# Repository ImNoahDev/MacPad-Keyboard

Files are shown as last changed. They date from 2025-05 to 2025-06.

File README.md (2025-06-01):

# The MacPad

The MacPad is a full sized keyboard designed for use with a Mac. The keyboard has 2 rotary encoders and a single fader for custom controls. The keyboard is designed to be used with QMK,

It can use any Alps or Cherry MX switches with optional through hole LEDs for backlighting.

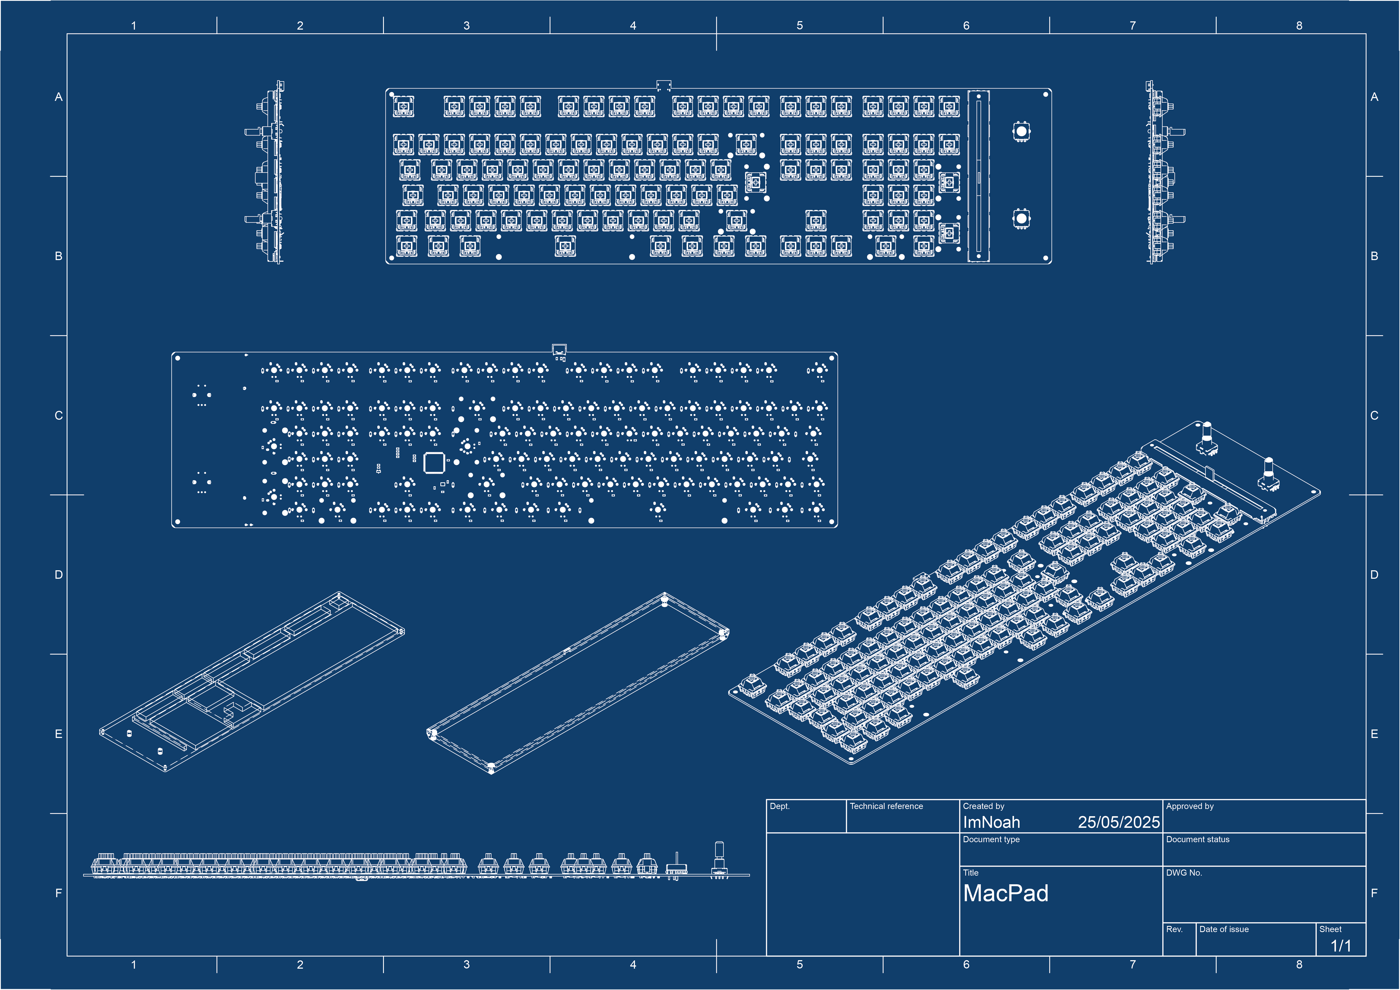
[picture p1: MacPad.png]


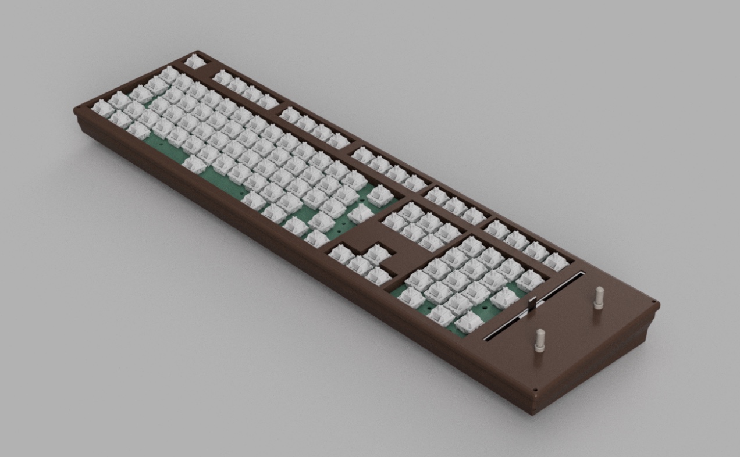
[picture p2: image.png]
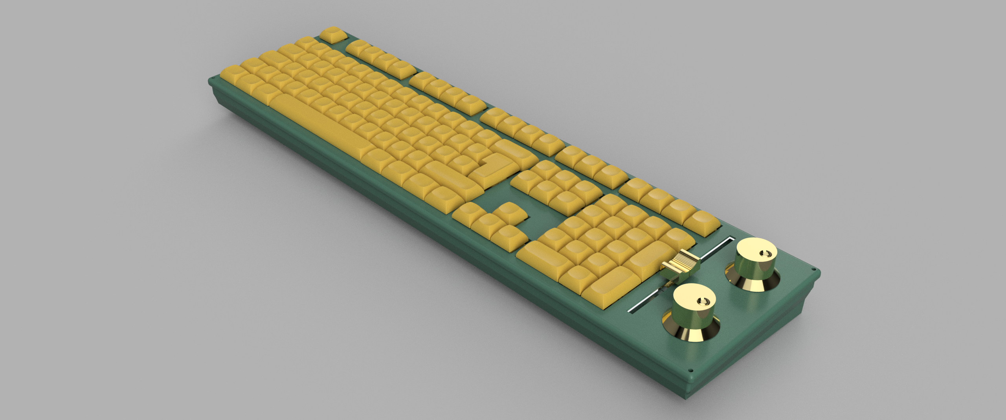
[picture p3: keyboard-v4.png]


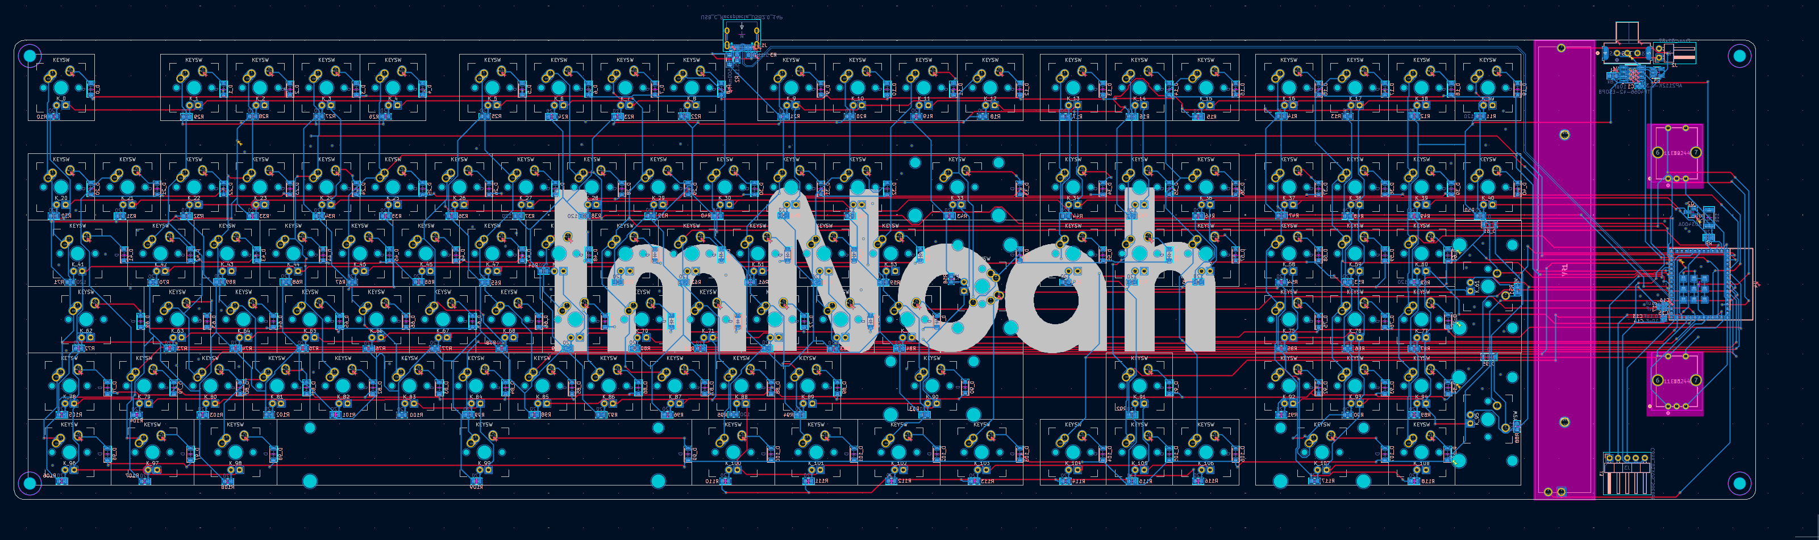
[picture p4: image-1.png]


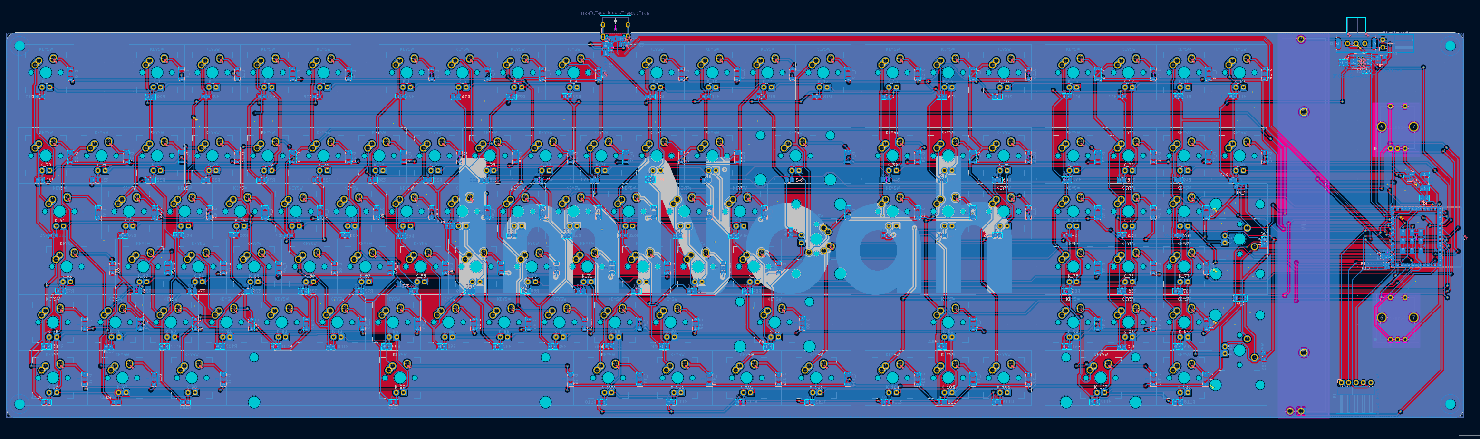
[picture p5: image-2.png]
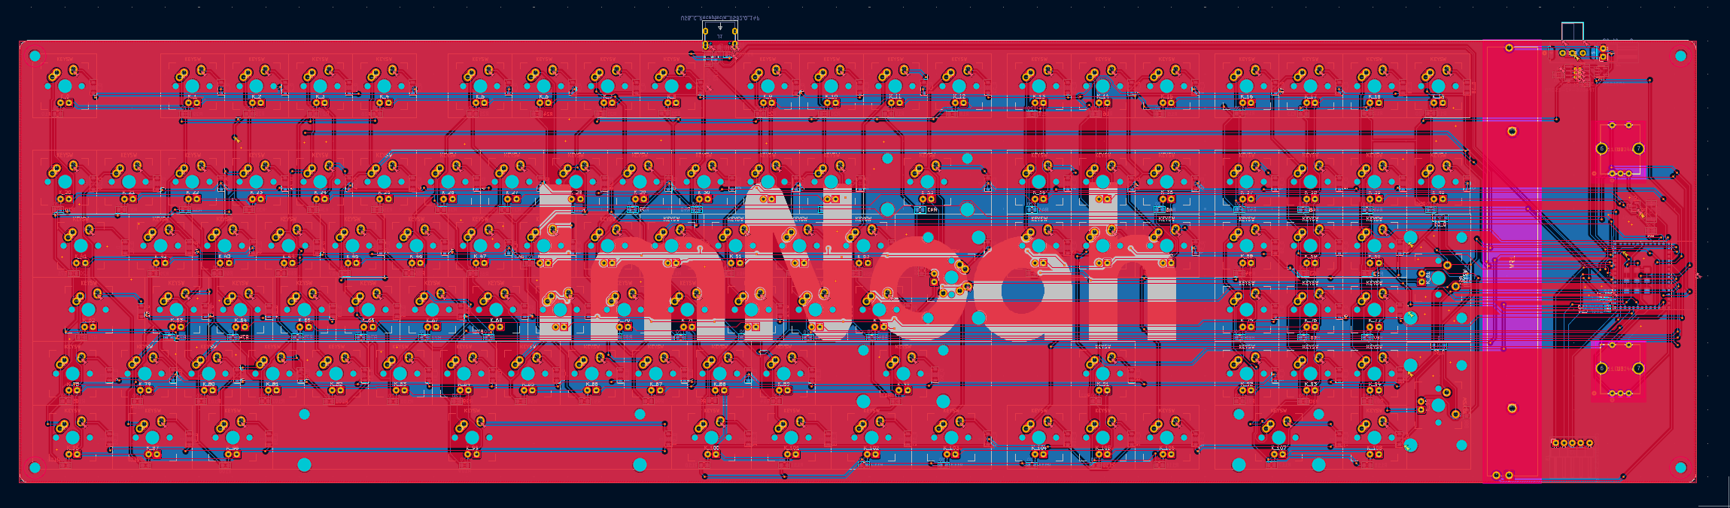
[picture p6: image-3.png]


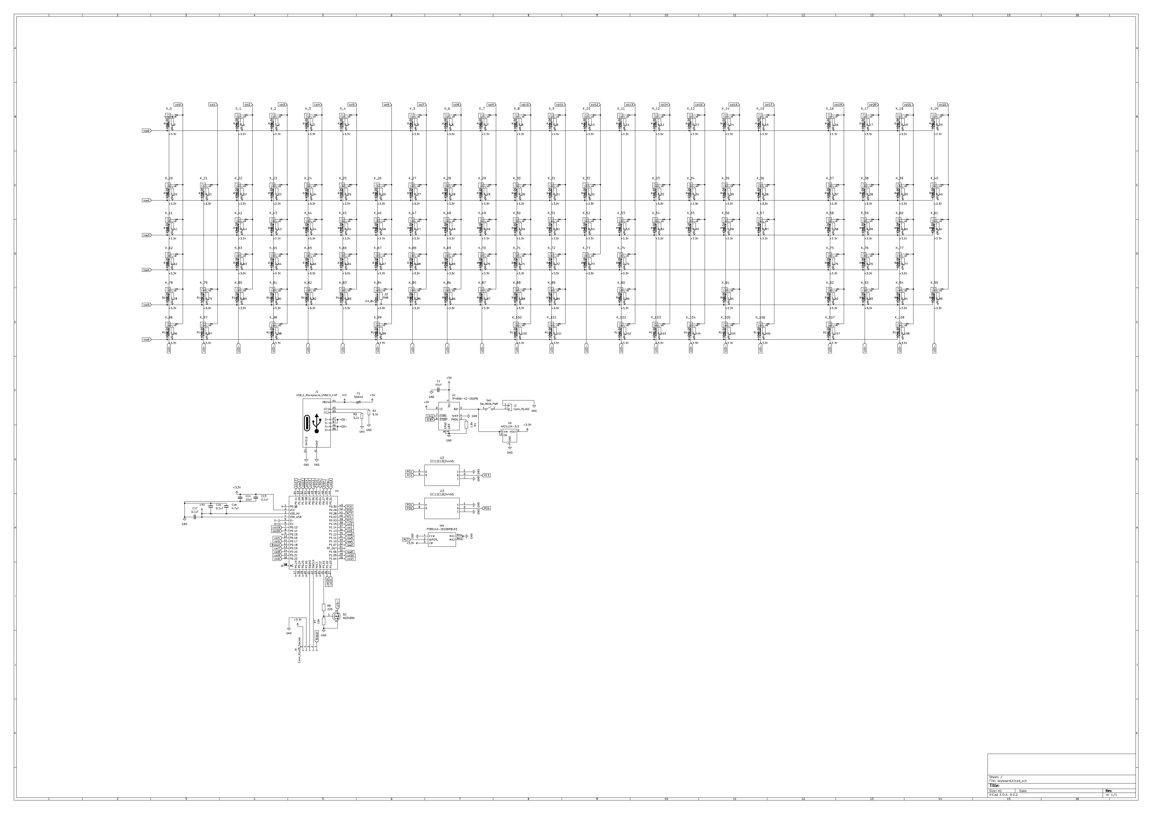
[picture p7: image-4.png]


## Assembly

The Plate must first be soldered underneath the switches (see plate.ai)

The PCB screws into the base with M3 screws and the top of the case screws ontop.

QMK firmware + configuration must be flashed using the macpad.hex file. The reset button can be pressed on the keyboard to put it into flashing mode and to flash the firmware. the F18 button can then be used as a reset button after the initial flash.

## BOM

| Item name | Item price | Item use | URL |
| --- | --- | --- | --- |
| PCB | $34 | PCB manufacture | pcbway.com |
| PCB components | $13 | Assemble controller on keyboard + rotary encoder/fader | pcbway.com |
| PCB Assembly | $30 | Assemble PCB | pcbway.com |
| Keyboard switches | $30 | Make the keyboard keyboard | [Keyswitches](https://www.keychron.uk/products/keychron-super-switch)  |
| Black fillament | $24 | Print the case | https://uk.store.bambulab.com/products/petg-hf?id=42010450329660 |
| Battery | $10.78 | Battery power | https://www.amazon.co.uk/EEMB-Battery-rechargeable-Connector-Certified |
| Total: | $142.71 | | |

## PCB component breakdown

| Designator | Quantity | Value | Footprint | Package | MPN | DNP | Mount_Type | Description | Price | Total | URL |
| --- | --- | --- | --- | --- | --- | --- | --- | --- | --- | --- | --- |
| C1, C2 | 2 | 22pF | C_0805_2012Metric | | | | smt | | $0.0011 | $0.0022 | https://jlcpcb.com/partdetail/1907-0402CG220J500NT/C1555 |
| C3 | 1 | 1uF | C_0805_2012Metric | | | | smt | | $0.0032 | $0.0064 | https://jlcpcb.com/partdetail/1944-CL10A105KO8NNNC/C1592 |
| C4, C5, C6 | 3 | 0.1uF | C_0805_2012Metric | | | | smt | | $0.0011 | $0.0033 | https://jlcpcb.com/partdetail/1877-CL05B104KO5NNNC/C1525 |
| C7 | 1 | 10uF | C_0805_2012Metric | | | | smt | | $0.0028 | $0.0028 | https://jlcpcb.com/partdetail/2043-CL10A106MQ8NNNC/C1691 |
| D_0, D_1, D_10, D_100, D_101, D_102, D_103, D_104, D_105, D_106, D_107, D_108, D_11, D_12, D_13, D_14, D_15, D_16, D_17, D_18, D_19, D_2, D_20, D_21, D_22, D_23, D_24, D_25, D_26, D_27, D_28, D_29, D_3, D_30, D_31, D_32, D_33, D_34, D_35, D_36, D_37, D_38, D_39, D_4, D_40, D_41, D_42, D_43, D_44, D_45, D_46, D_47, D_48, D_49, D_5, D_50, D_51, D_52, D_53, D_54, D_55, D_56, D_57, D_58, D_59, D_6, D_60, D_61, D_62, D_63, D_64, D_65, D_66, D_67, D_68, D_69, D_7, D_70, D_71, D_72, D_73, D_74, D_75, D_76, D_77, D_78, D_79, D_8, D_80, D_81, D_82, D_83, D_84, D_85, D_86, D_87, D_88, D_89, D_9, D_90, D_91, D_92, D_93, D_94, D_95, D_96, D_97, D_98, D_99 | 109 | D | D_SOD-123 | | | | smt | | $0.0052 | $0.57 | https://jlcpcb.com/partdetail/Shunye-ES1D_SOD_123FL/C7370889 |
| F1 | 1 | 500mA | Fuse_1206_3216Metric | | | | smt | | $0.0365 | $0.0365 | https://jlcpcb.com/partdetail/JlcpcbAssembly-FUSE/C9900021114 |
| J1 | 1 | USB_C_Receptacle_USB2.0_14P | USB_C_Receptacle_HCTL_HC-TYPE-C-16P-01A | | | | smt | USB 2.0-only 14P Type-C Receptacle connector | $0.0365 | $0.0365 | https://jlcpcb.com/partdetail/JlcpcbAssembly-14P/C9900117666 |
| Q1 | 1 | AO3400A | SOT-23 | | | | smt | 30V Vds, 5.7A Id, N-Channel MOSFET, SOT-23 | $0.0428 | $0.0428 | https://jlcpcb.com/partdetail/Alpha_OmegaSemicon-AO3400A/C20917 |
| R1, R6, R7 | 3 | 10k | R_0805_2012Metric | | | | smt | Resistor | $0.0013 | $0.0039 | https://jlcpcb.com/partdetail/1841-1206W4J0103T5E/C1489 |
| R10, R100, R101, R102, R103, R104, R105, R106, R107, R108, R109, R11, R110, R111, R112, R113, R114, R115, R116, R117, R118, R12, R13, R14, R15, R16, R17, R18, R19, R20, R21, R22, R23, R24, R25, R26, R27, R28, R29, R30, R31, R32, R33, R34, R35, R36, R37, R38, R39, R40, R41, R42, R43, R44, R45, R46, R47, R48, R49, R50, R51, R52, R53, R54, R55, R56, R57, R58, R59, R60, R61, R62, R63, R64, R65, R66, R67, R68, R69, R70, R71, R72, R73, R74, R75, R76, R77, R78, R79, R80, R81, R82, R83, R84, R85, R86, R87, R88, R89, R90, R91, R92, R93, R94, R95, R96, R97, R98, R99 | 109 | 120 | R_0805_2012Metric | | | | smt | Resistor | $0.0008 | $0.0872 | https://jlcpcb.com/partdetail/23514-0603WAF1200T5E/C22787 |
| R2, R3 | 2 | 5.1k | R_0805_2012Metric | | | | smt | | $0.0007 | $0.0014 | https://jlcpcb.com/partdetail/Yageo-RC0603JR075K1L/C14677 |
| R4, R5 | 2 | 22 | R_0805_2012Metric | | | | smt | | $0.0005 | $0.001  | https://jlcpcb.com/partdetail/1555-0603WAJ0220T5E/C1203 |
| R8 | 1 | 220 | R_0805_2012Metric | | | | smt | Resistor | $0.0004 | $0.0004 | https://jlcpcb.com/partdetail/1463-RC02W221JT/C1111 |
| SW1 | 1 | SW_Push | SKQG-1155865 | | | | smt | | $0.2385 | $0.2385 | https://jlcpcb.com/partdetail/Panasonic-EVQQ2B03W/C79178 |
| U1 | 1 | RF-BM-ND06 | | | | | smt | | $5 | $5 | https://jlcpcb.com/partdetail/rfstar-RF_BMND06/C5125838 |
| U2, U3 | 2 | EC11E18244A5 | EC11E18244A5_ALPS | | | | tht | | $1.9785 | $3.96 | https://jlcpcb.com/partdetail/Alpsalpine-EC11E18244A5/C255515 |
| VR1 | 1 | PTB0143-2010BPB103 | PTB01432010BPB103 | | PTB0143-2010BPB103 | | tht | Bourns PTB0143-2010BPB103 1 Gang Slide Carbon Potentiometer, 10k, +/-20%, 0.5W, Linear | $5.5140 | $5.5140 | https://jlcpcb.com/partdetail/Bourns-PTB01432010BPB103/C17183742 |
| Y1 | 1 | 16MHz | Crystal_SMD_3225-4Pin_3.2x2.5mm | | | | smt | | $0.0356 | $0.0356 | https://jlcpcb.com/partdetail/Yxc_CrystalOscillators-X322516MOB4SI/C12668 |
| | | | | | | | | | Total:  | $23.93  | |

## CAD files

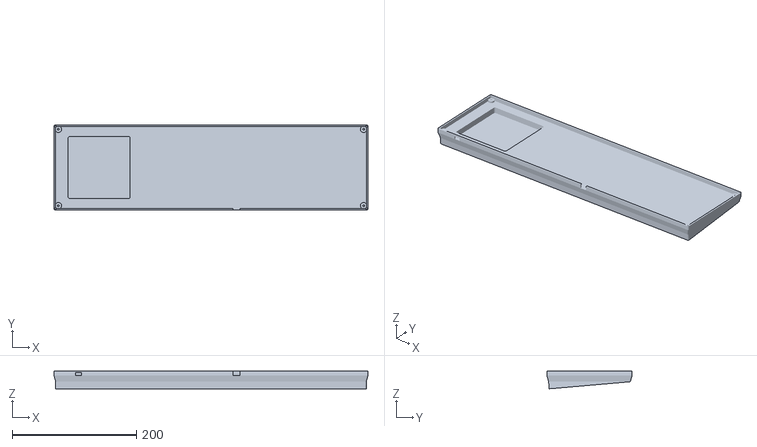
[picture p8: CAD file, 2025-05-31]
CAD/Keyboard lid.stl
505.0 x 137.0 x 28.4

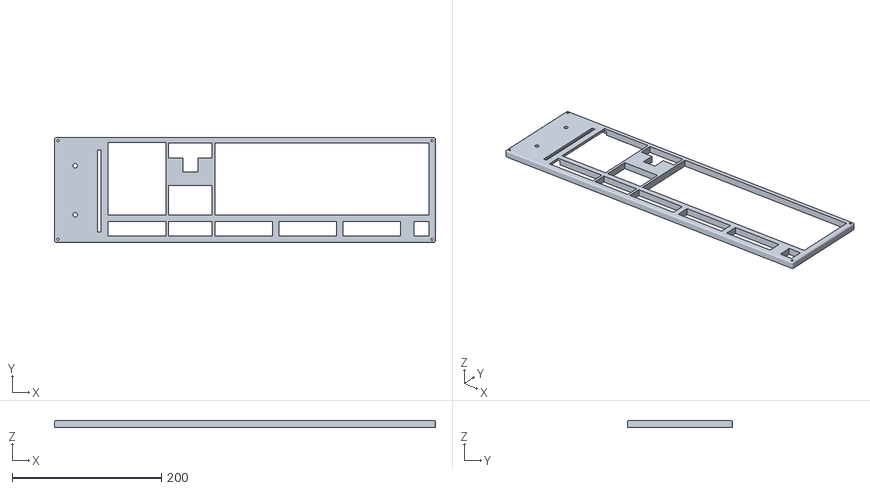
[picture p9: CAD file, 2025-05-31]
CAD/Keyboard Base.stl
510.0 x 141.0 x 9.60

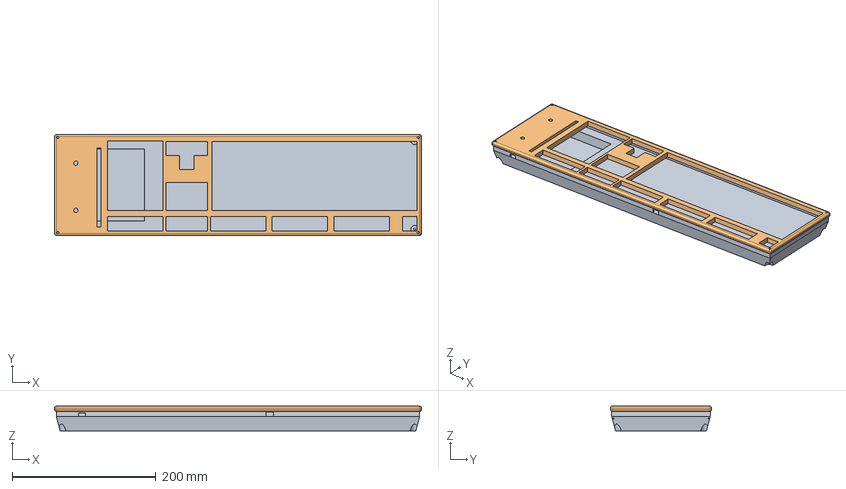
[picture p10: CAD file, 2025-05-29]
CAD/Keyboard.step
510.0 x 141.0 x 34.6 mm

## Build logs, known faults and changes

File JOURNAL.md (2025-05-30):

Total Hours: 23

##  Initial layout (2 hours)

I have researched Apple and apple clone keyboards. 

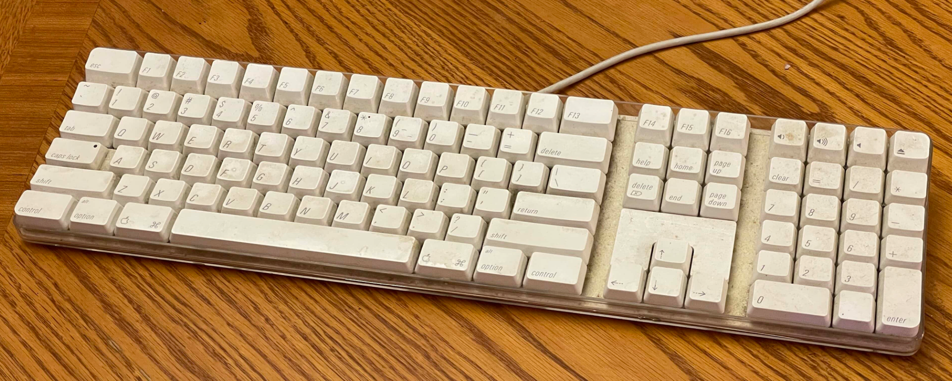
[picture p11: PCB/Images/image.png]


I will be baseing my keyboard off of this design with a few added features.

New features:

- USB-C power
- Mechanical switches
- Rotary encoders
- volume fader

I started by mapping my keyboard matrix. I am using MX alps hybrid footprints to give a wider range of options for switches.

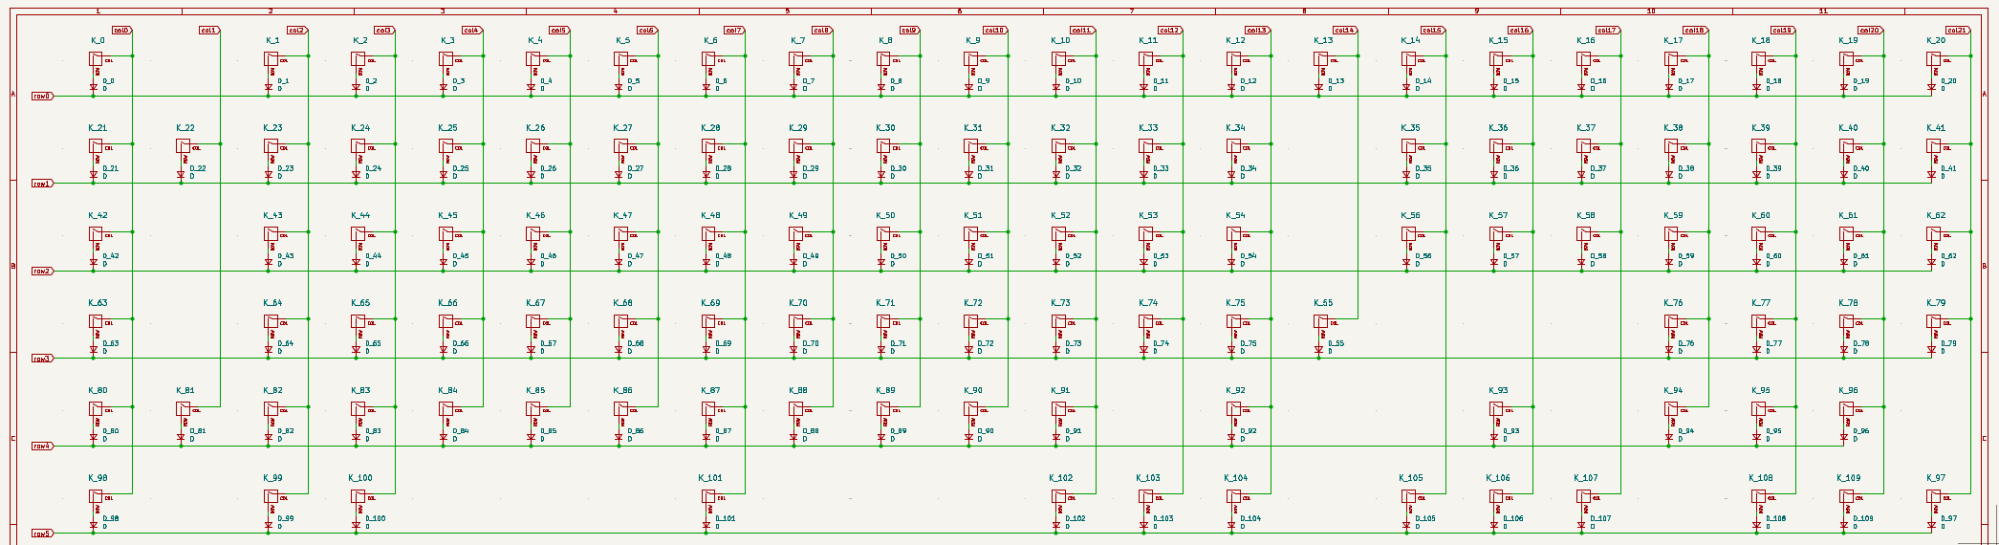
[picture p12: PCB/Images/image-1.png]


This layout closely mimics the original layout with few changes. Having that finished, I have begun to research QMK compatible controllers for the next step.

##  Microcontroller (2 hours)

I am using an AT90USB1286 controller (due to its USB functionality and QMK compatibility). The controller is connected to a 16mhz crystal for timing. The CC pins on the USB-C port are pulled down to ground via 5.1k resistors to follow the USB-C specification. I have 2 rotary encoders (EC11) and the special feature of my project, a fader for volume control. Capacitors 1 to 7 are used for decoupling and filtering.

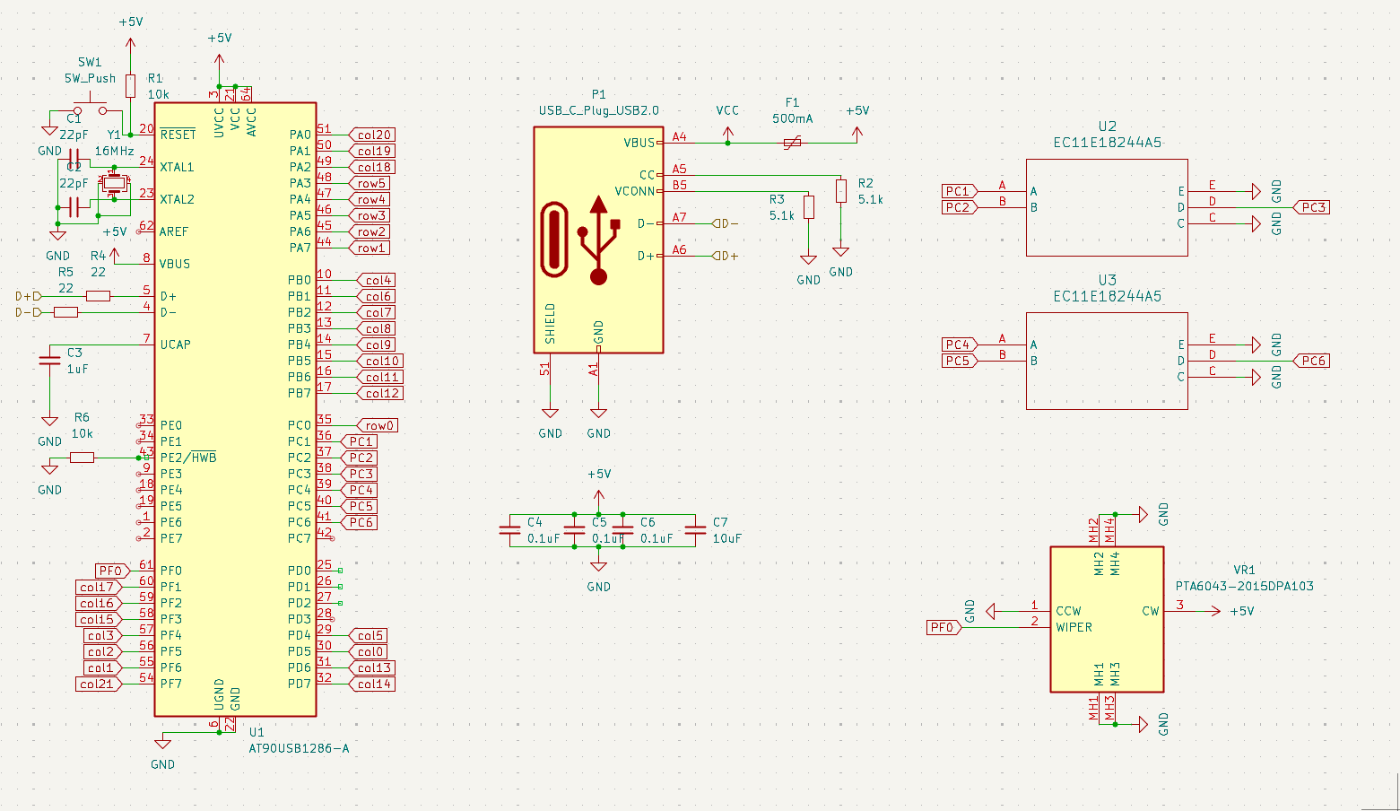
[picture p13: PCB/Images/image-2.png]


The columns from the layout have been connected here to the matrix above. I have also conencted up the two rotary encoders and the slider fader. 

##  Layout (2 hours)

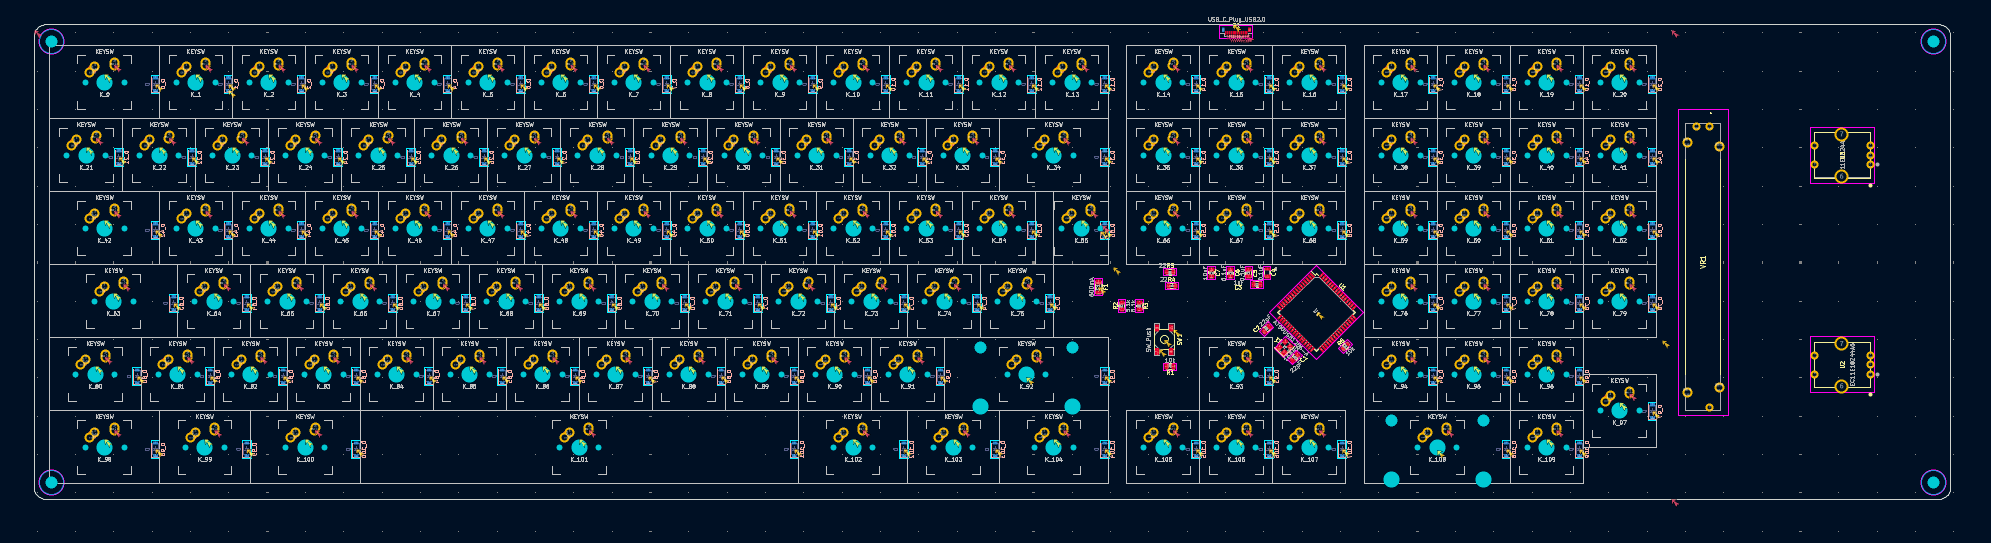
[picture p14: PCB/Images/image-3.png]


Next i laid out the keyboard in the most optimal format for the space. This format allows me to make versions with and without the fader + rotary encoders. I also rounded the PCB edges and added 3.2mm screw holes for mounting inside a case. I have ensured the pcb is less than 50cm long to ensure it can be assembled with many assembly services.

## Back to the drawing board (2 hours)

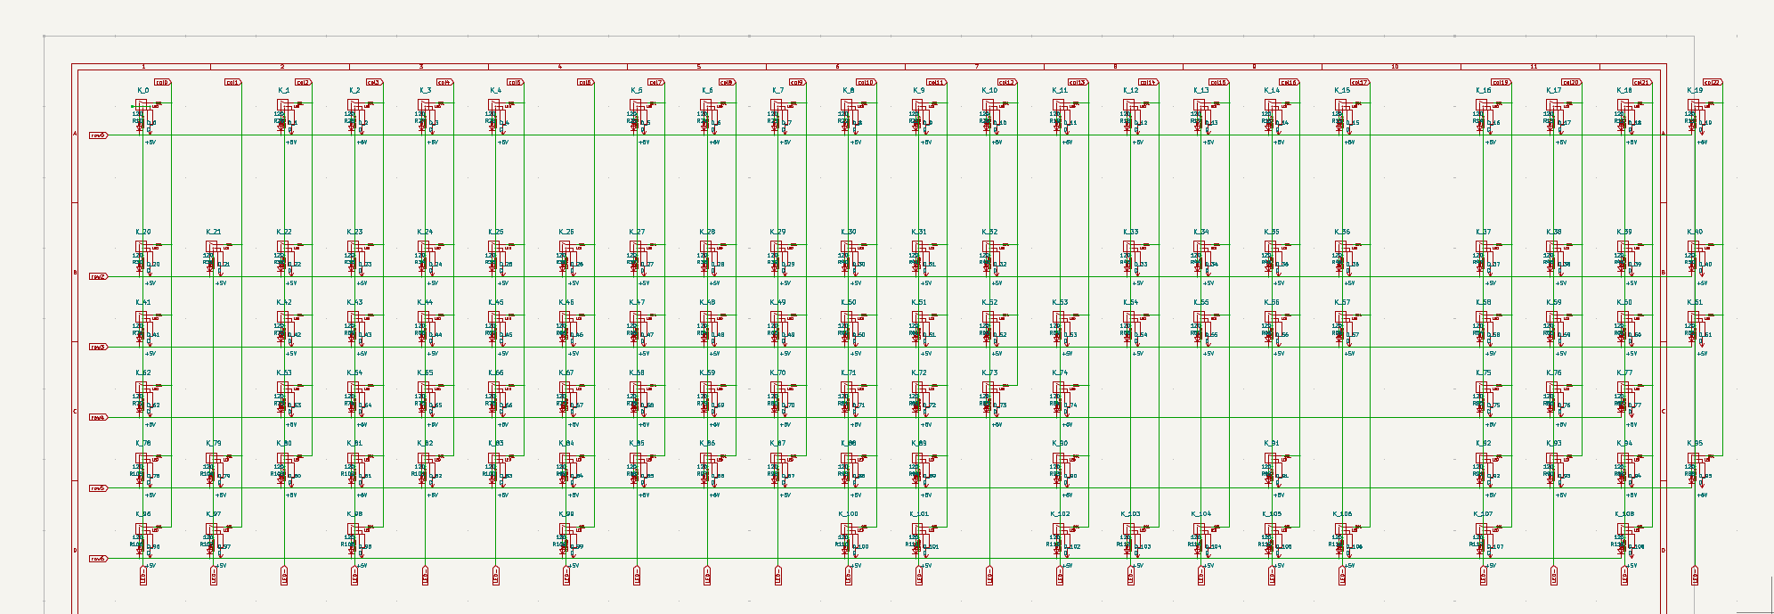
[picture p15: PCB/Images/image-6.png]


Due to using a non standard layout, I found it would be impossible to get keycaps for some keys (such as my thin iso key). I am instead using a more standard layout. Because of the saved money from doing this, I can now add LEDs. I have added a backlight led matrix that can be controlled via the MCU. I have created my new layout, connected it to the MCU schematic and added LEDS with a driver.

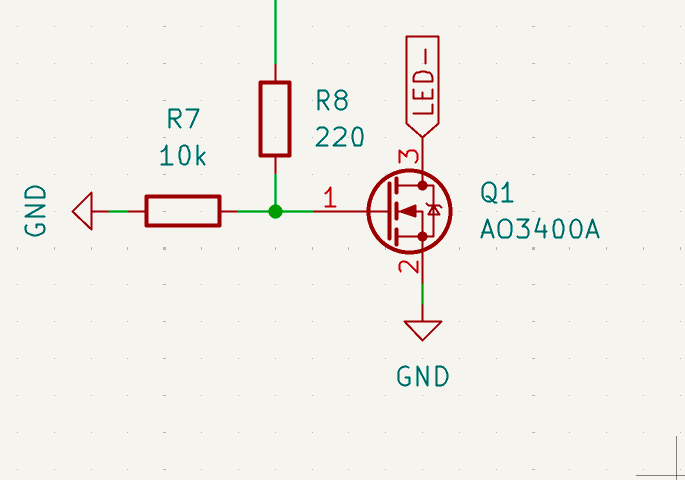
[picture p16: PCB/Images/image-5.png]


## New Layout (2 hours)

I laid out the PCB again with the new logic for the LEDs.

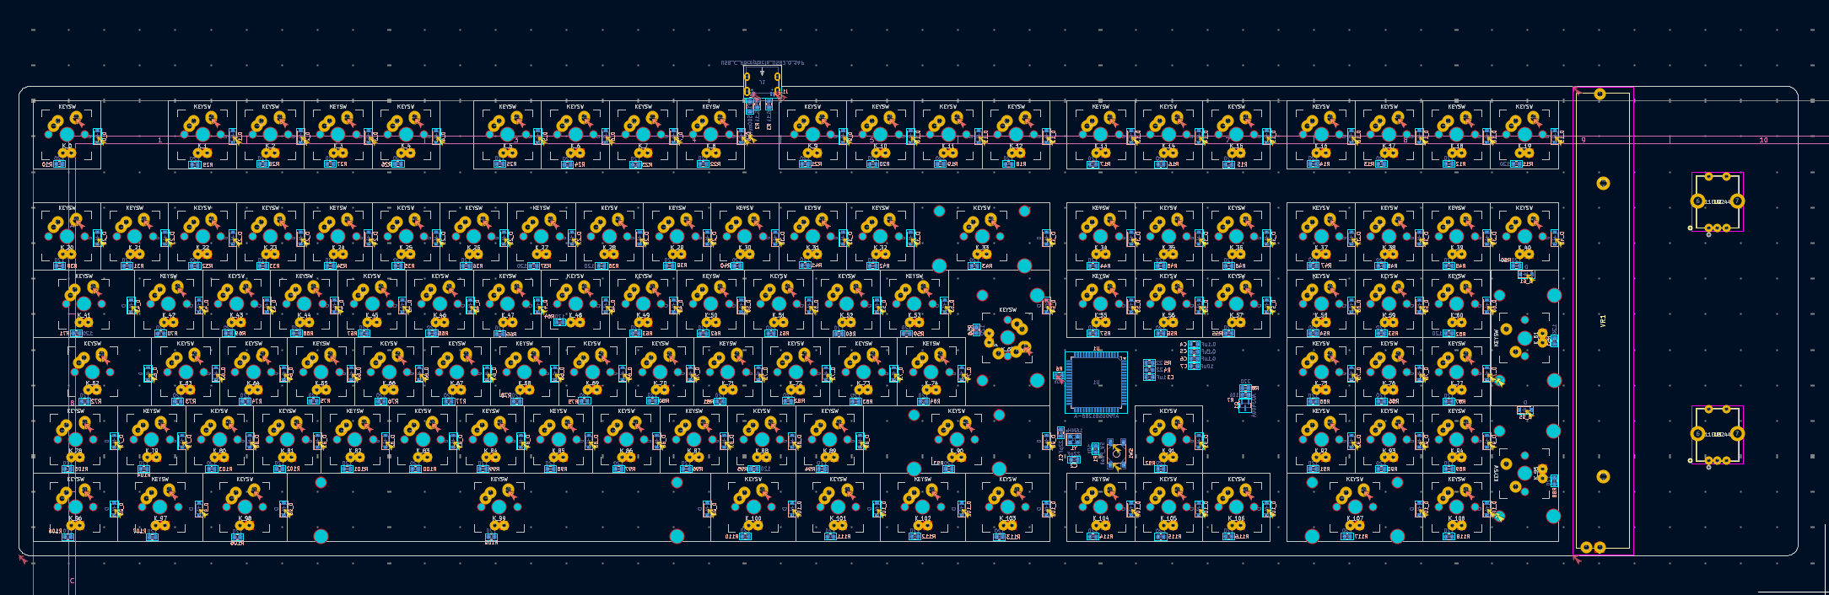
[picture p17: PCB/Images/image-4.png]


I have added a resistor to 5v for each led and laid the pcb out similar to before.

## Routing (2 hours)

I routed the PCB and added a ground plane.

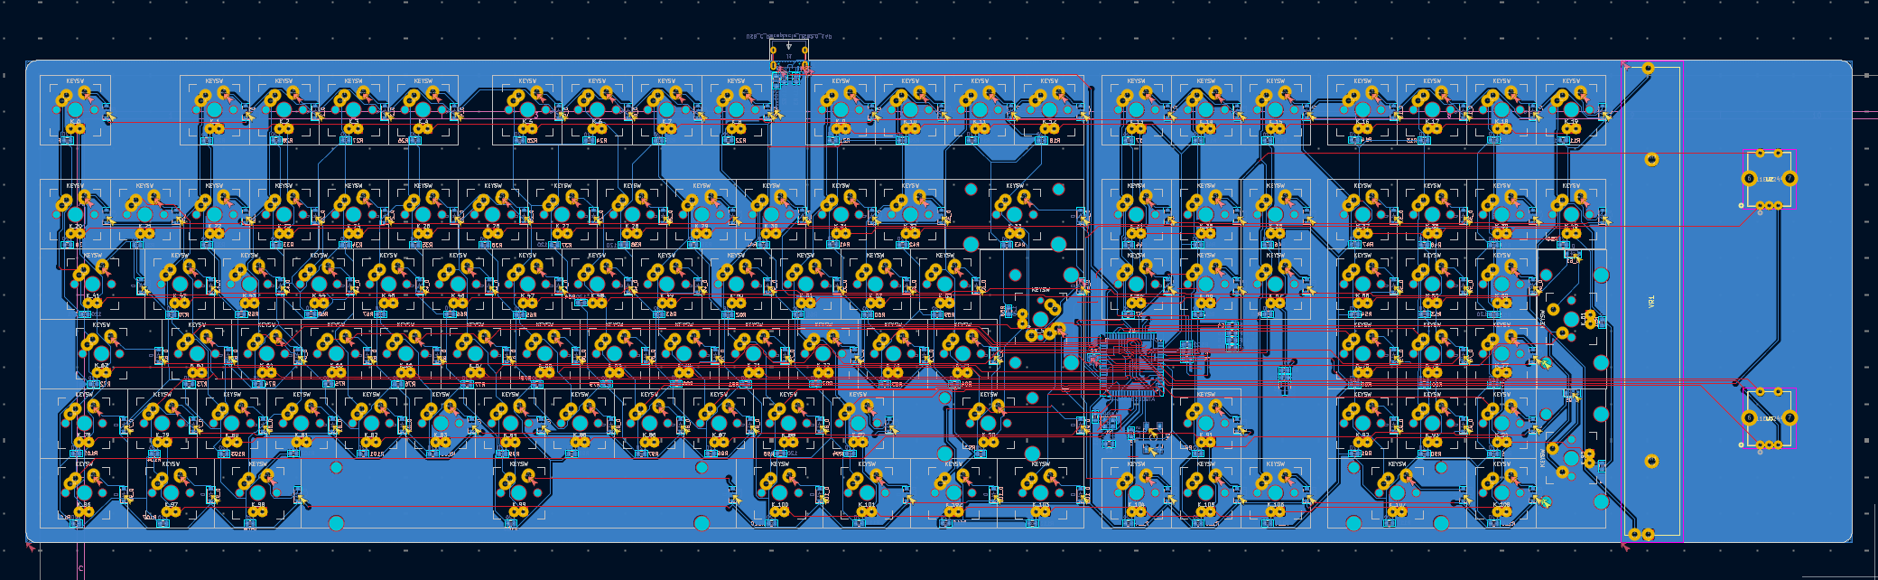
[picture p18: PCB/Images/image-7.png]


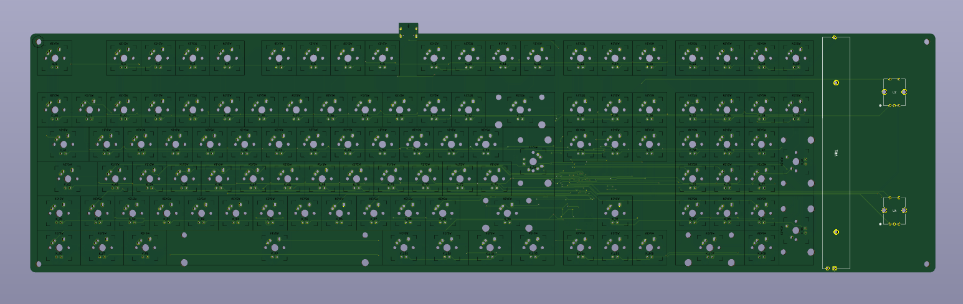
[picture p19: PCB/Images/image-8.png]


Although my ground plane is missing from a large part of the PCB, it still links all ground traces together well. I also added 4x m3 screw holes for mounting.

## Plate (1 hour)

Next I created a plate for my keyboard. First I created my schematic in KLE and used a tool to convert KLE to SVG for the plate. I then matched this up with a plotted version of my pcb silkscreen. I then drew the full border, added holes for mounting and added holes for my special components.

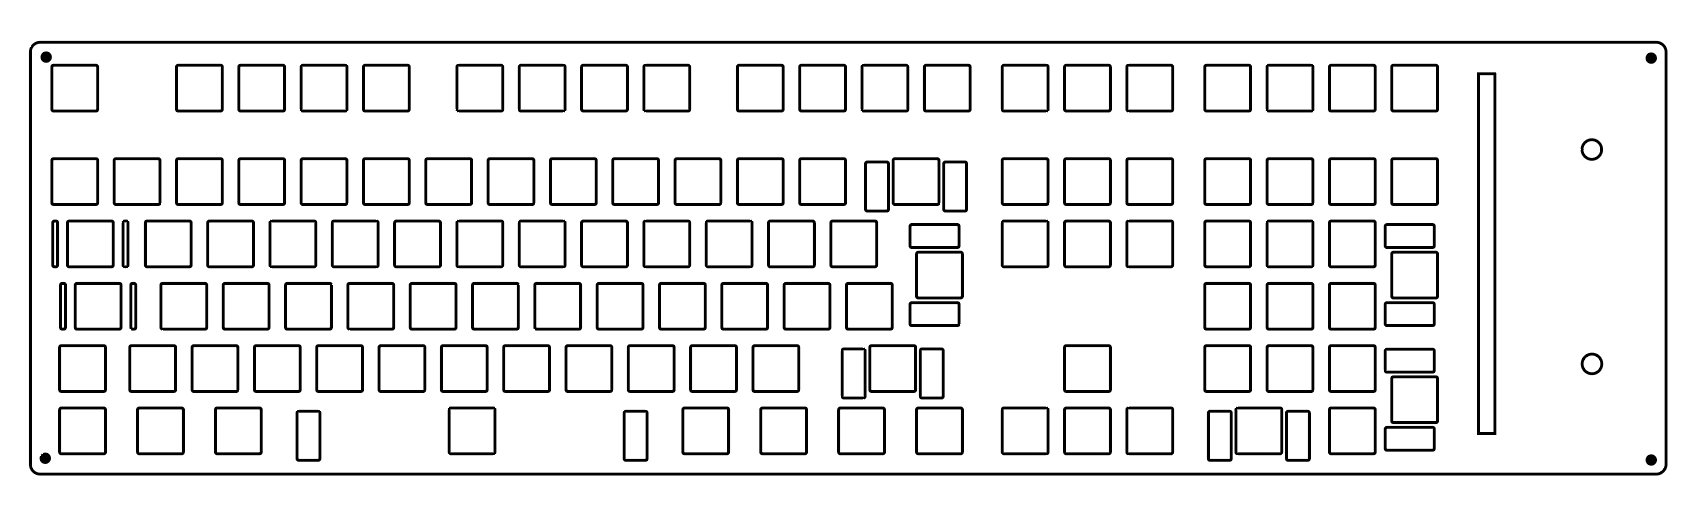
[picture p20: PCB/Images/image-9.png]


Next I will begin to design a case for my PCB.

## Case (1.5 hours)

I designed a case for my PCB My case fully fits my USBc port and will fit my PCB with plate. This case can be 3d printed in 2 parts and is assembled with m3 screws.

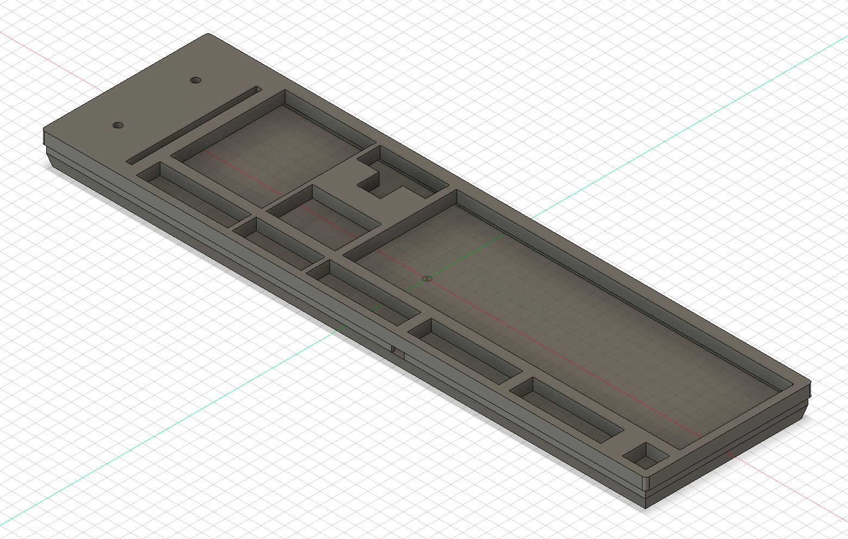
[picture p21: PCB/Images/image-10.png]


## Firmware (1 hour)

I mapped the keyboard in QMK and added the hex file for flashing. I also swapped the backlight and a column pin to have them on the correct pins.

## Polishing (1 hour)

Added a render of the PCB and case together. Rounded some edges on the case. Added holes for rubber feet.

## New controller (1 hour)

I have replaced the controller with the more readily available STM32F103ZETx due to cost.

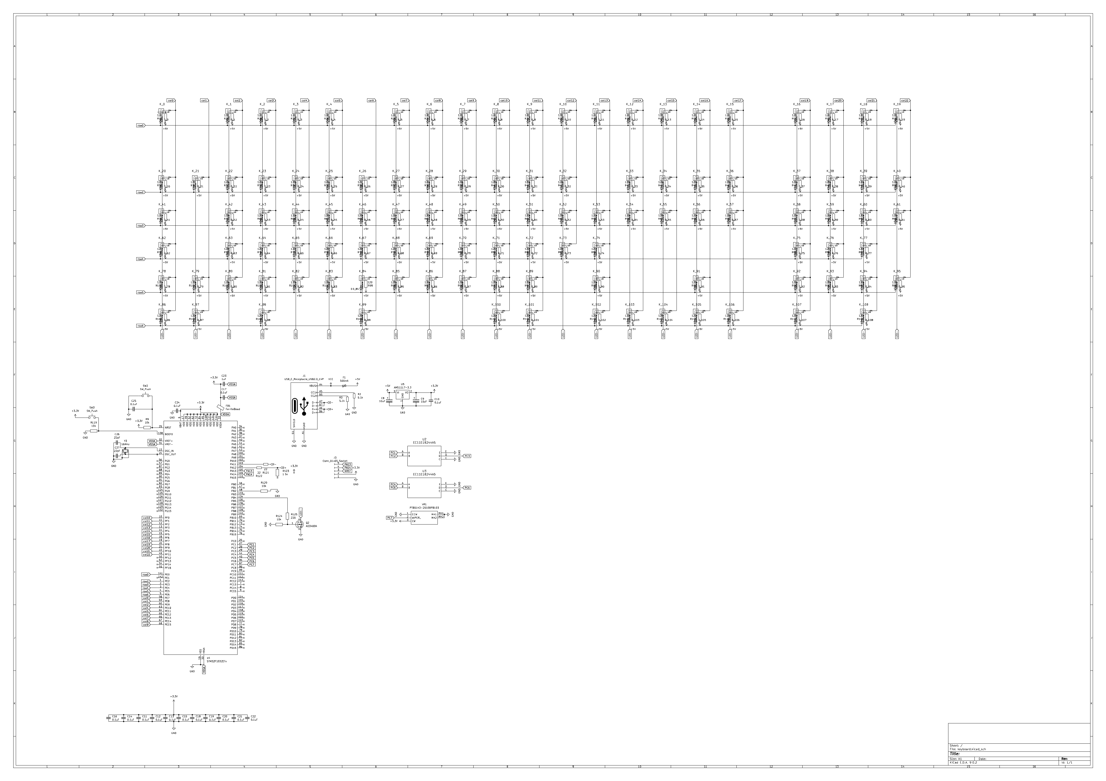
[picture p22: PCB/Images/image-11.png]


## Bluetooth and Battery (2 hours)

This involved finding a ZMK compatible bluetooth chip. I chose the NRF52840-QIAA-R as it is a commonly used chip. I then wired this int he same way as my previous STM32. I am using a 3MHz crystal and have designed a Pi network for my antenna using (in theory) optimal values based on the data sheet.

I have also added a TP4056 battery controller and a 3.3v regulator for battery power to allow wireless use.

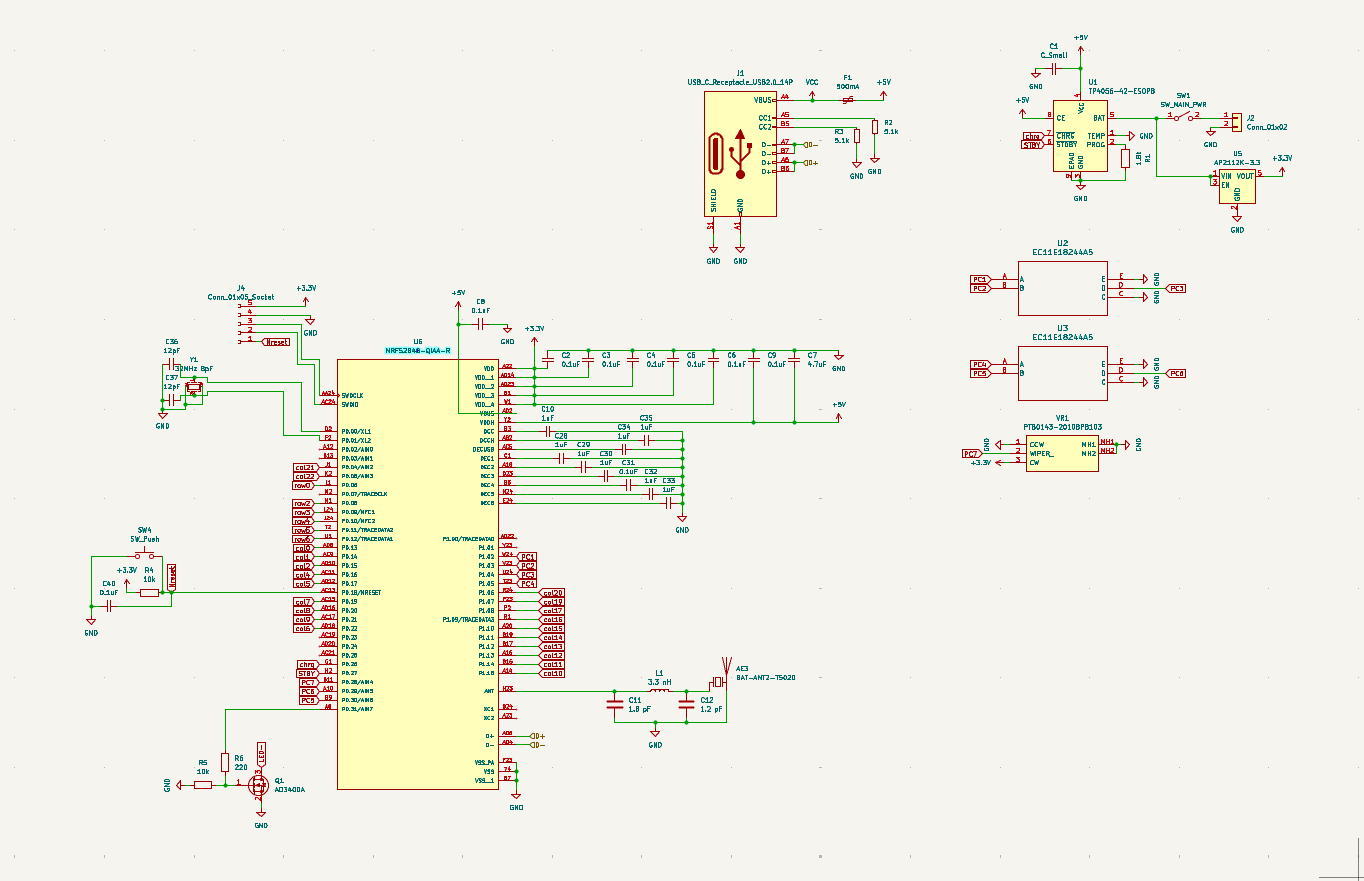
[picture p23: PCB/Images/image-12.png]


## Attempt 3 (2 hours)

Unfortunately i was unable to route the antenna circuitry without printing the board to perform initial tests so i am instead using a RF-BM-ND06 System on board. This makes my design more simple and more reliable. My schamtic now has bluetooth and battery power implimented.

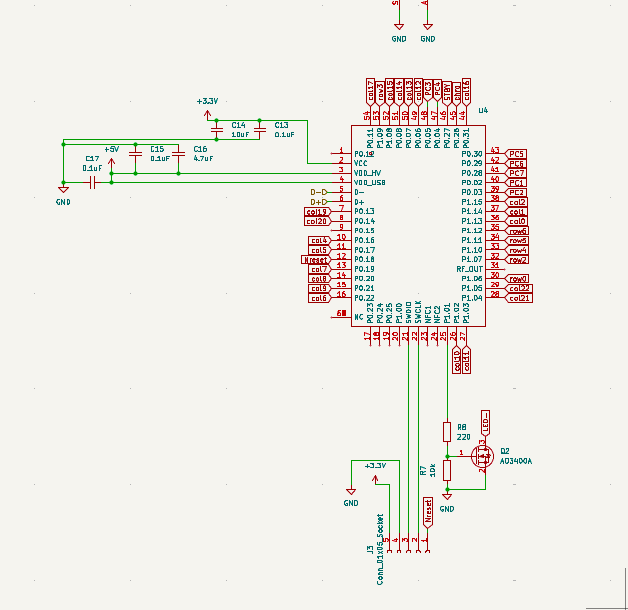
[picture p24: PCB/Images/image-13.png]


## Routing (1 hour)

Routed the PCB after laying out the components again.

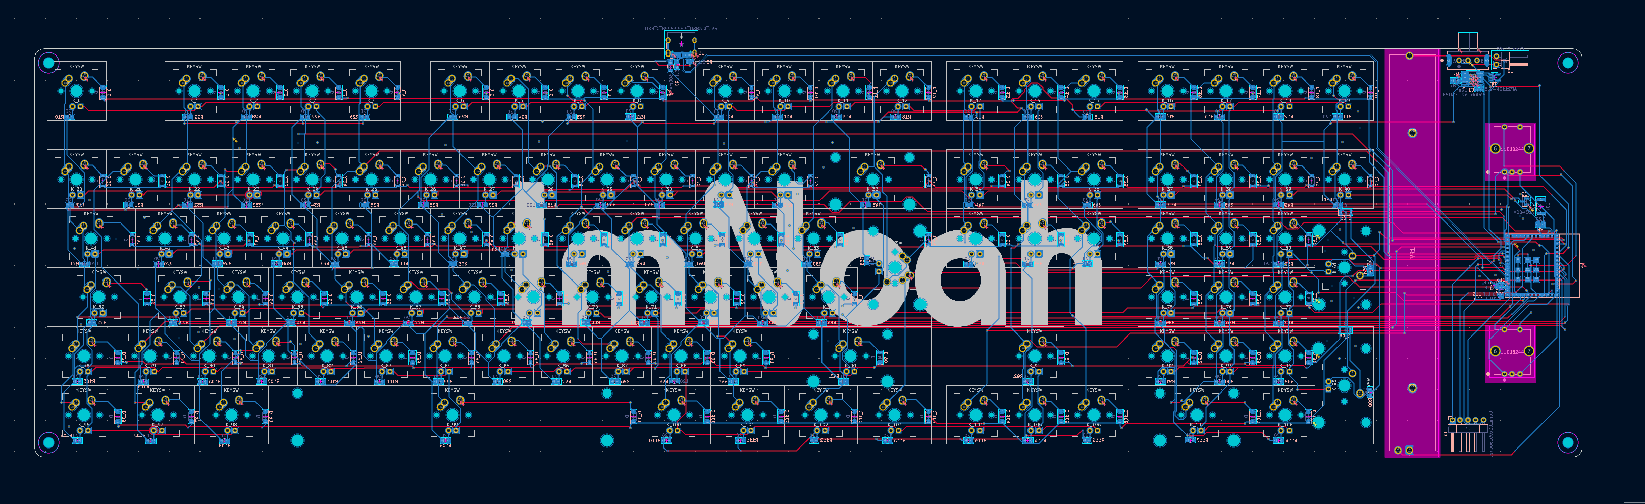
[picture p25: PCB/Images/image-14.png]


## Case (0.5 hours)

I extended the depth of the case and added a lot to make room for the battery. I then added a hole for the SPST power switch. The battery hole is of sufficient size for any size of battery and an adhesive backing to be chosen.

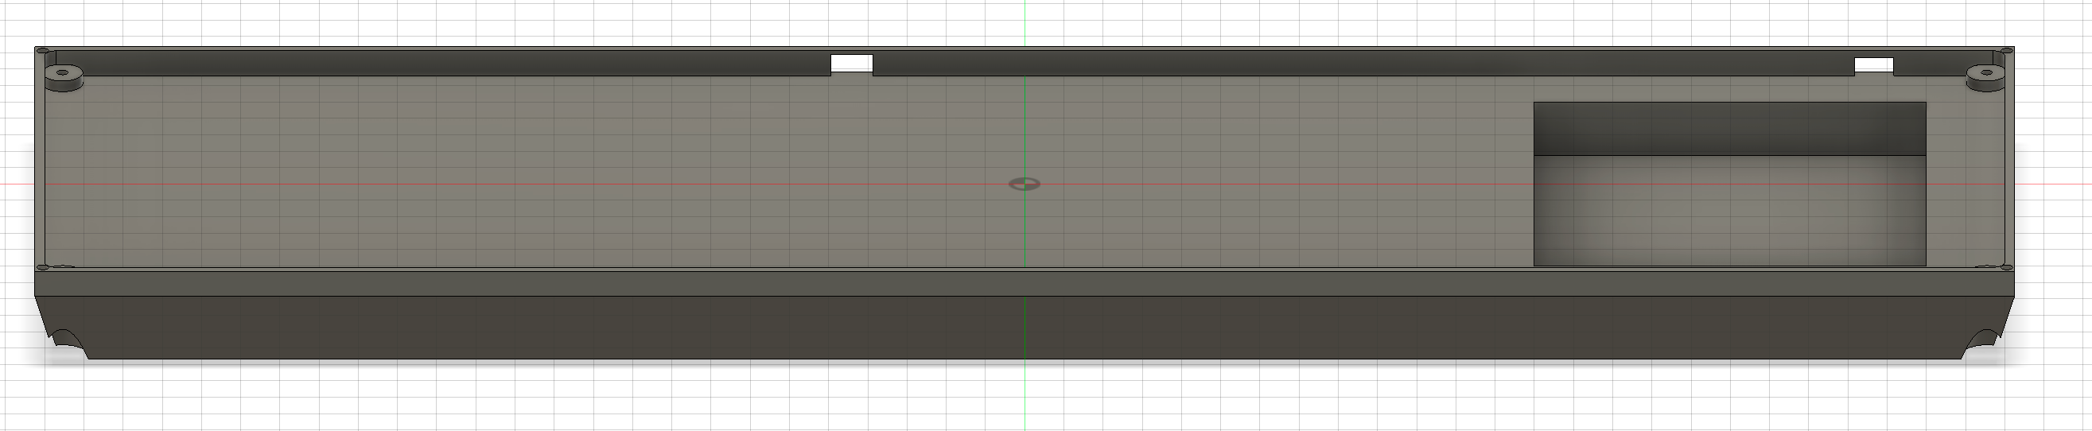
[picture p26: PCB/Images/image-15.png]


## Case (0.5 hours)

I fixed the issue where the screw holes come out the bottom, I also added a slanted base to allow it to sit at a 5* angle. The case is also thinner now to make it easier to print. I also rounded the internal angles in the battery comparentment corners for fun. I have added the inserts for 10mm rubber feet onto the slanted bottom again. I also rounded the outer corners to make the keyboard easier to carry.

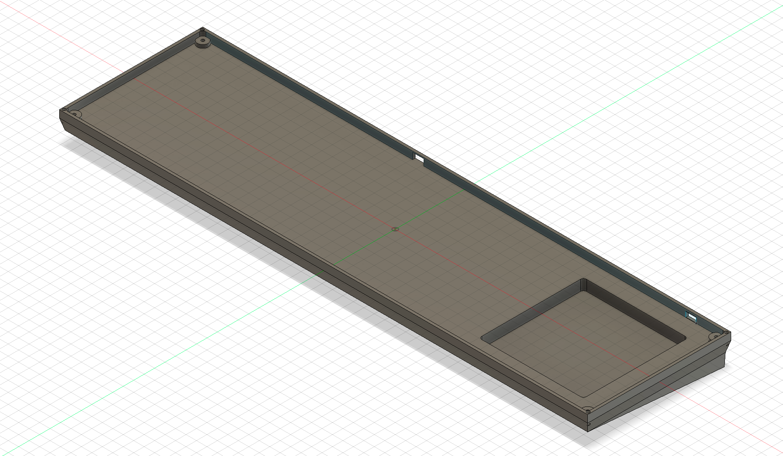
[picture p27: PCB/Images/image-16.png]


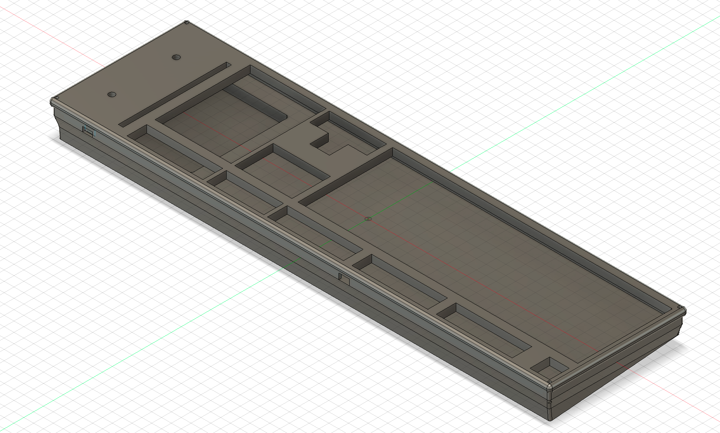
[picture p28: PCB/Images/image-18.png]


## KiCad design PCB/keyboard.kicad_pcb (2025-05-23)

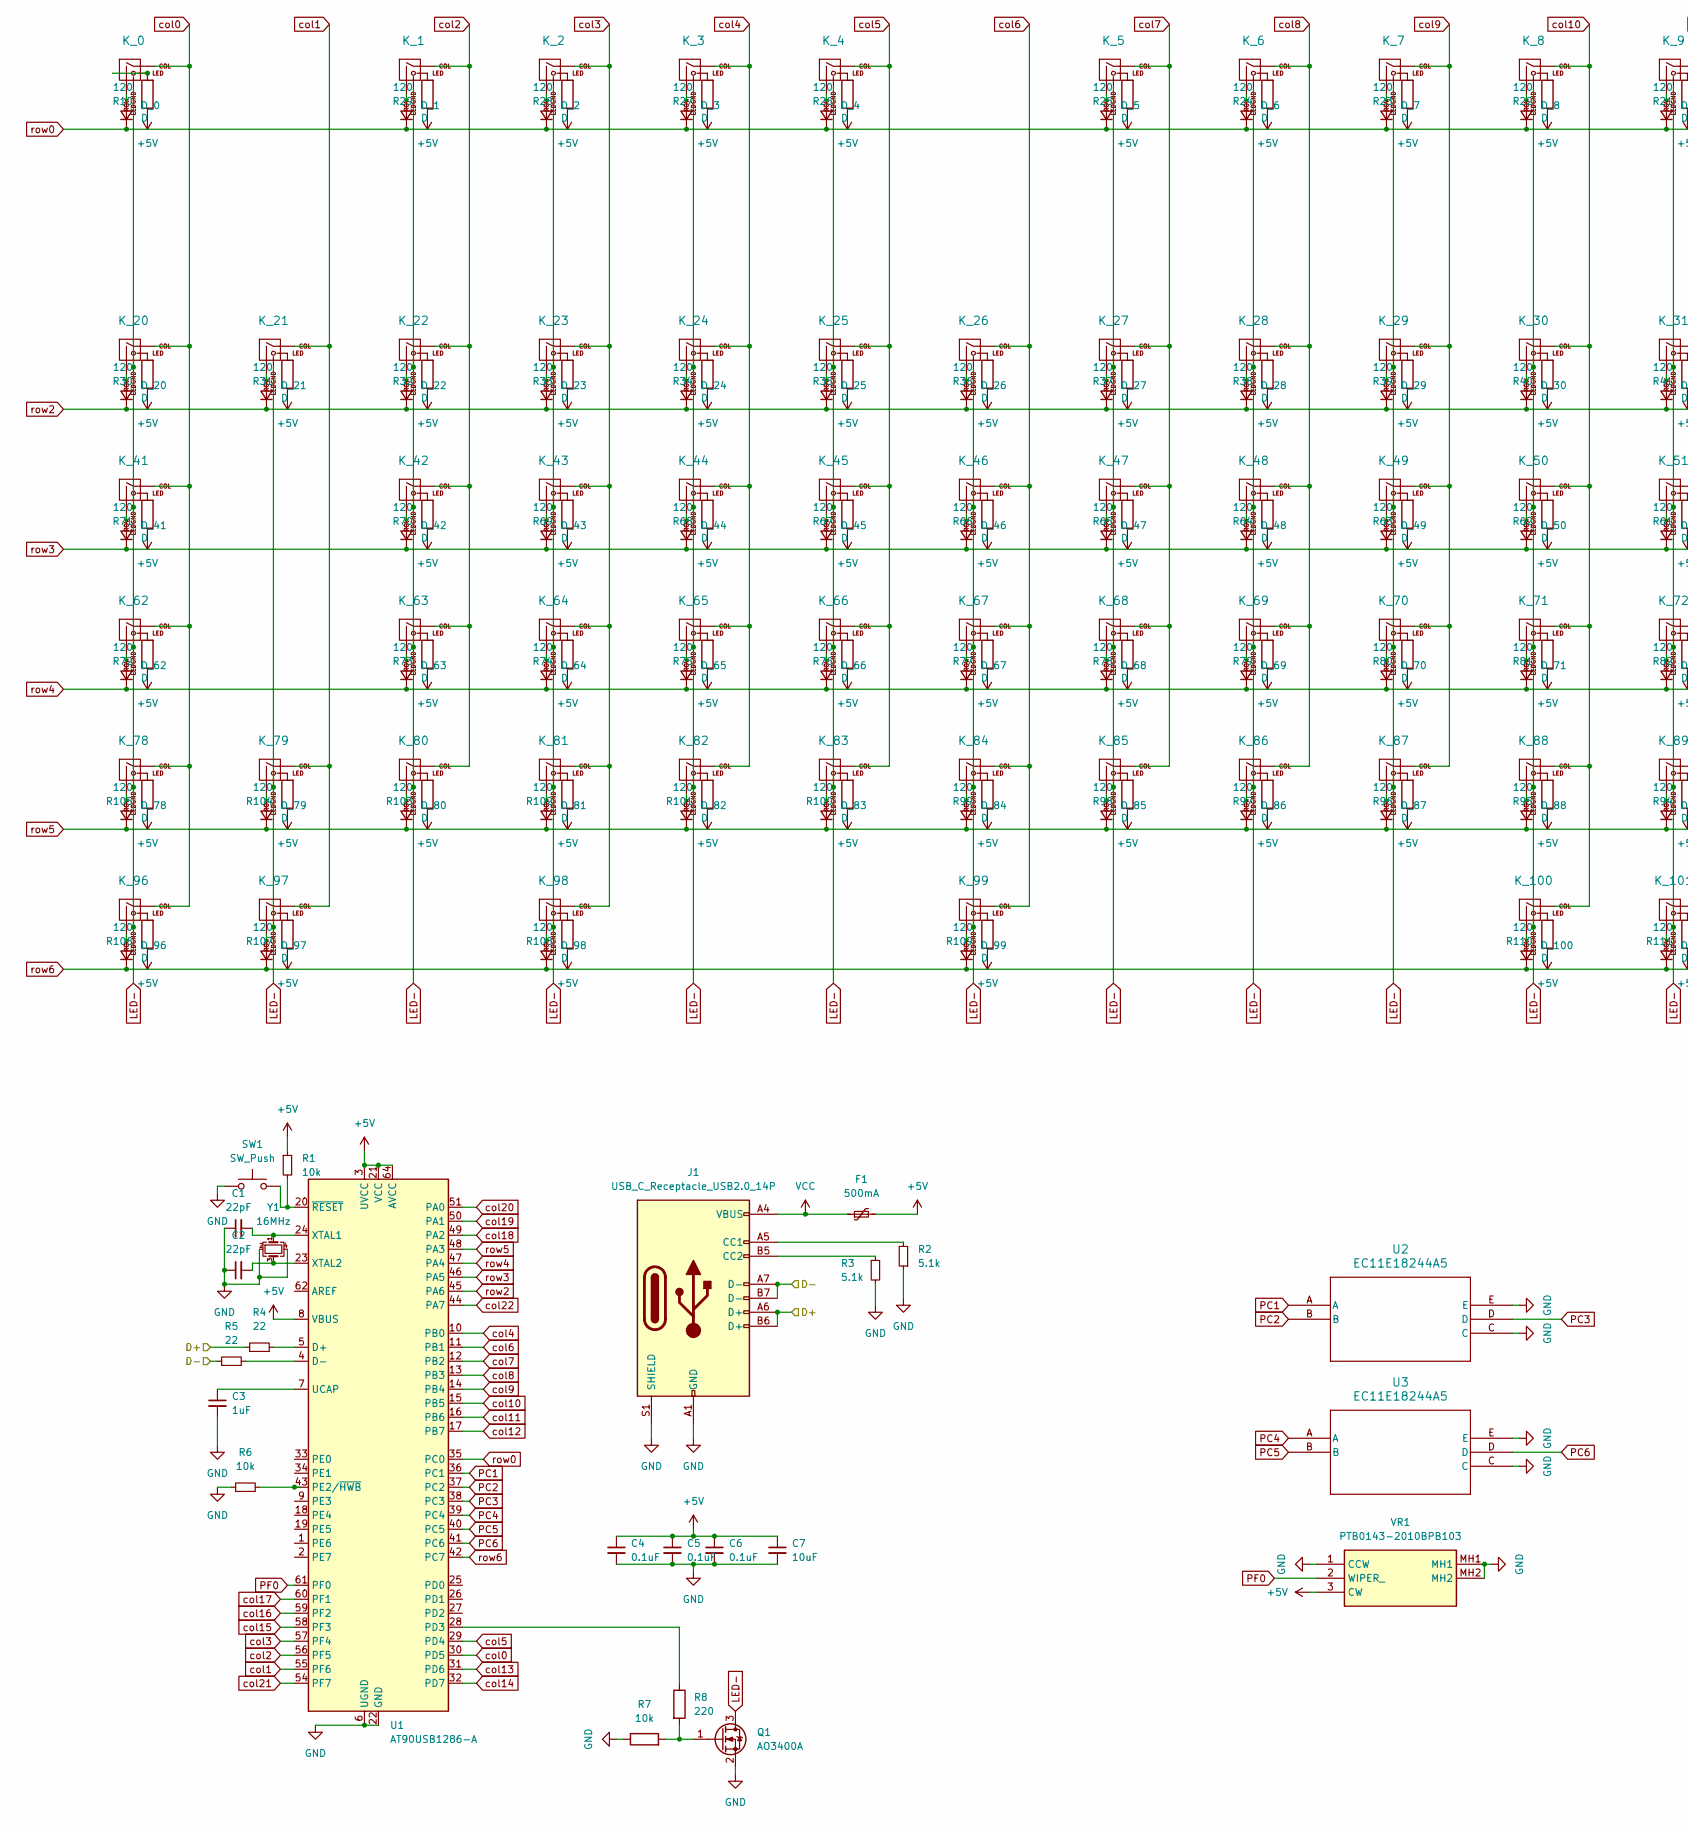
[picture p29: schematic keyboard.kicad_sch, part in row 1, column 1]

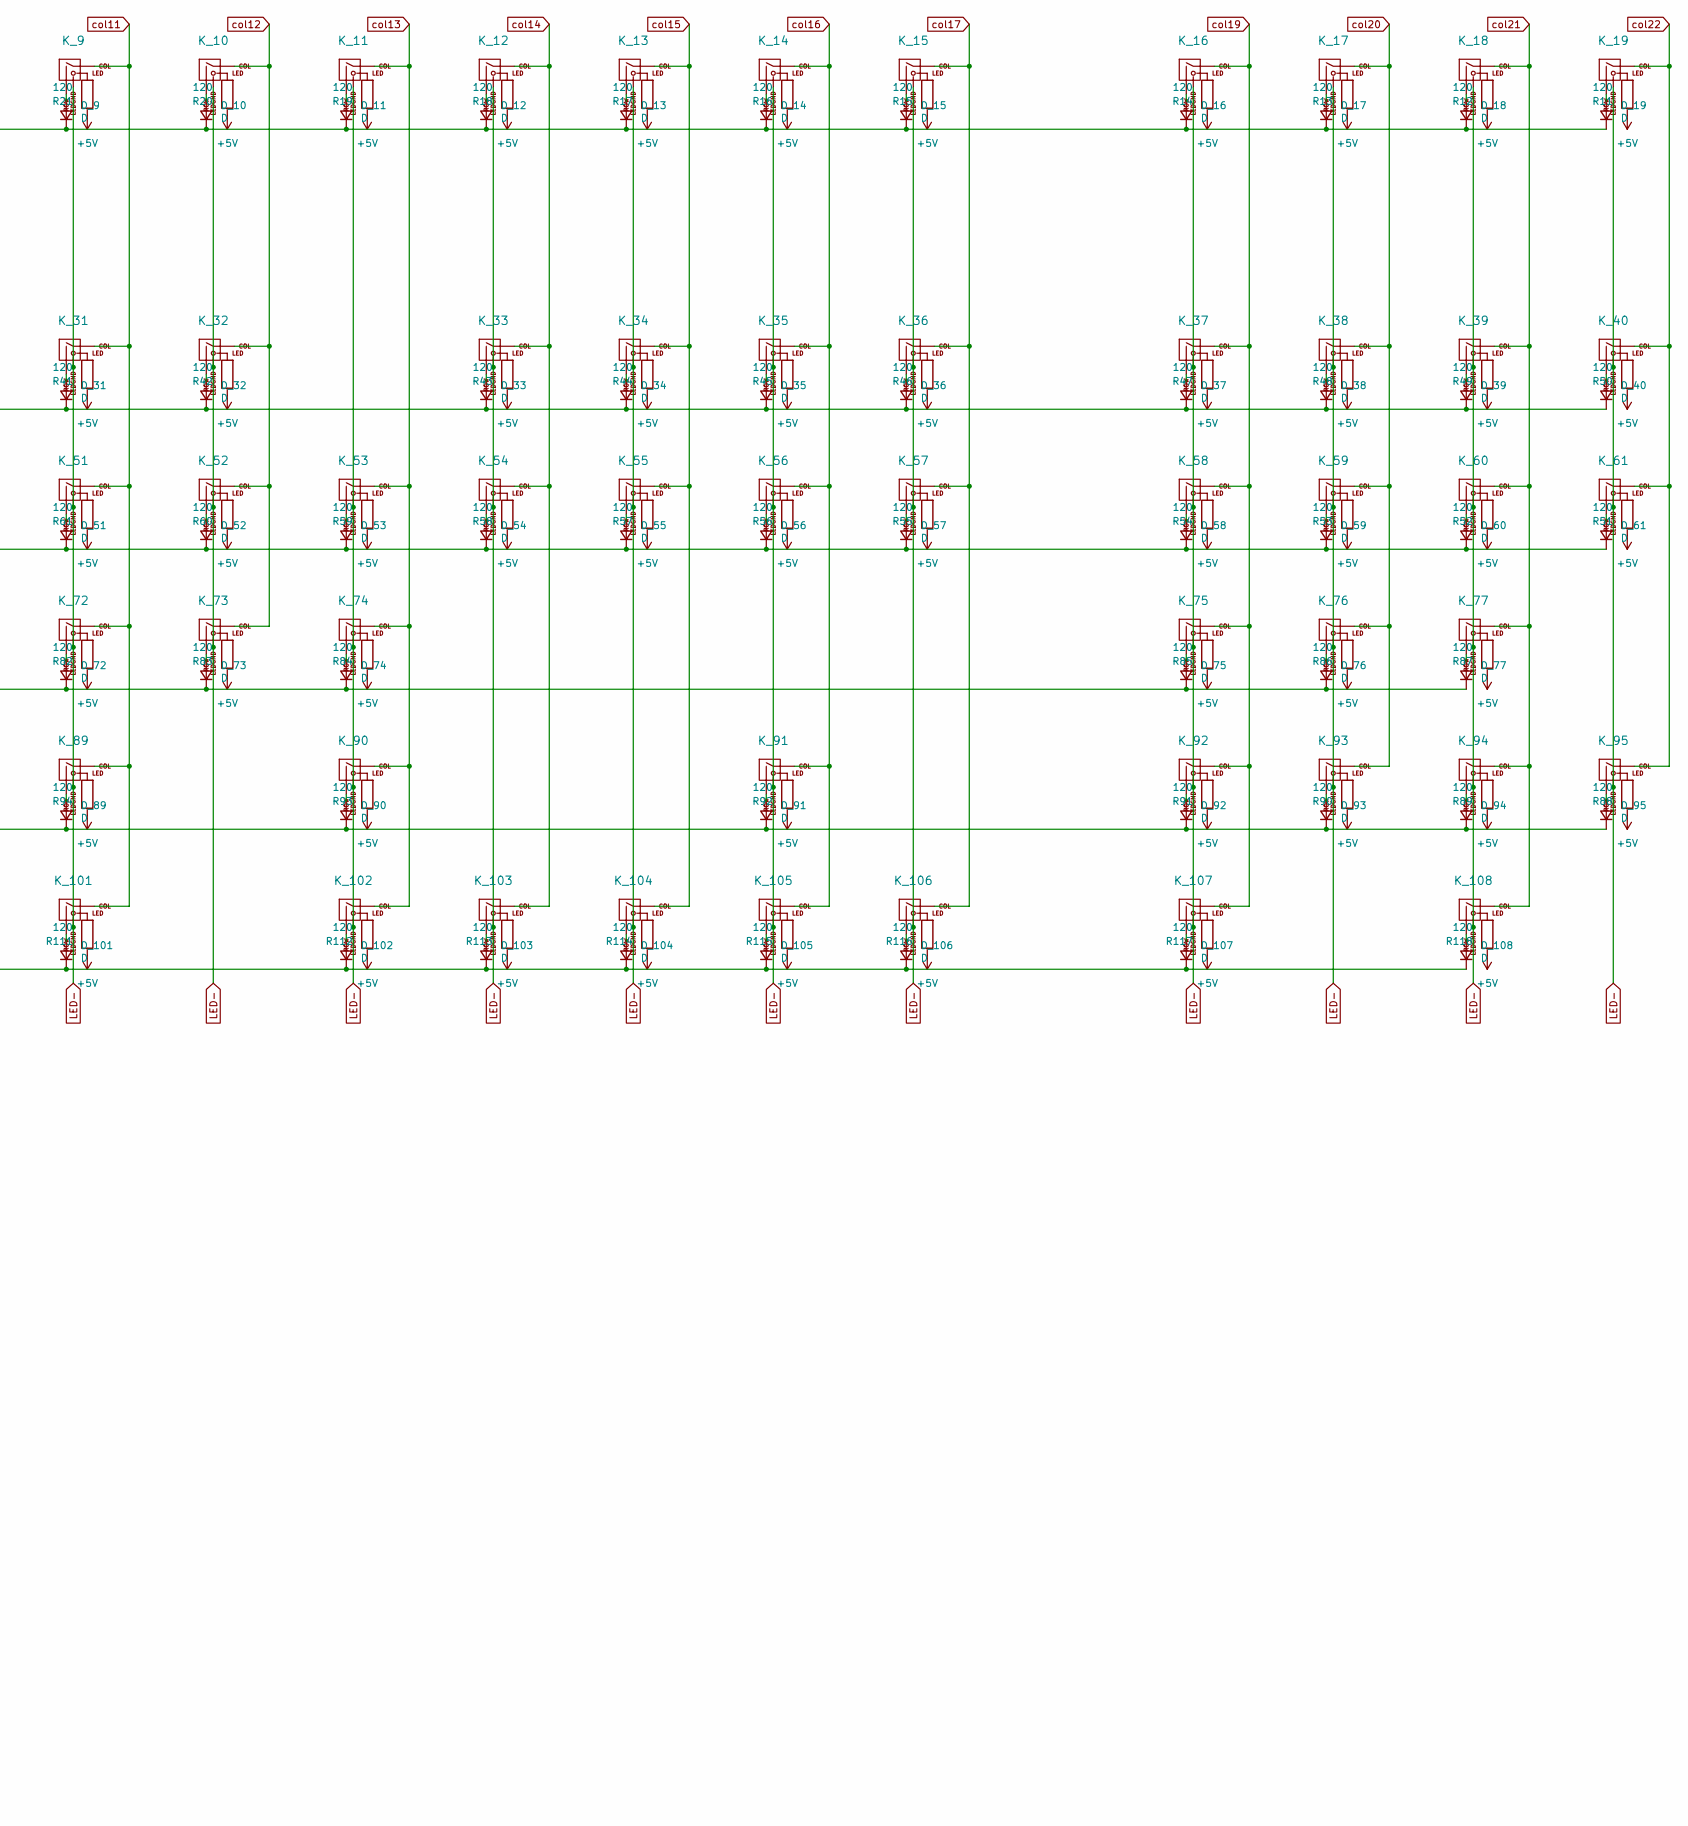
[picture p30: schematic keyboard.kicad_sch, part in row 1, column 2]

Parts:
C1, C2: 22pF; C_0805_2012Metric
C3: 1uF; C_0805_2012Metric
C4, C5, C6: 0.1uF; C_0805_2012Metric
C7: 10uF; C_0805_2012Metric
D_0, D_1, D_2, D_3, D_4, D_5, D_6, D_7, D_8, D_9, D_10, D_11, D_12, D_13, D_14, D_15, D_16, D_17, D_18, D_19, D_20, D_21, D_22, D_23, D_24, D_25, D_26, D_27, D_28, D_29, D_30, D_31, D_32, D_33, D_34, D_35, D_36, D_37, D_38, D_39, D_40, D_41, D_42, D_43, D_44, D_45, D_46, D_47, D_48, D_49, D_50, D_51, D_52, D_53, D_54, D_55, D_56, D_57, D_58, D_59, D_60, D_61, D_62, D_63, D_64, D_65, D_66, D_67, D_68, D_69, D_70, D_71, D_72, D_73, D_74, D_75, D_76, D_77, D_78, D_79, D_80, D_81, D_82, D_83, D_84, D_85, D_86, D_87, D_88, D_89, D_90, D_91, D_92, D_93, D_94, D_95, D_96, D_97, D_98, D_99, D_100, D_101, D_102, D_103, D_104, D_105, D_106, D_107, D_108: D; D_SOD-123
F1: 500mA; Fuse_1206_3216Metric
J1: USB_C_Receptacle_USB2.0_14P; USB_C_Receptacle_HCTL_HC-TYPE-C-16P-01A
K_0, K_1, K_2, K_3, K_4, K_5, K_6, K_7, K_8, K_9, K_10, K_11, K_12, K_13, K_14, K_15, K_16, K_17, K_18, K_19, K_20, K_21, K_22, K_23, K_24, K_25, K_26, K_27, K_28, K_29, K_30, K_31, K_32, K_34, K_35, K_36, K_37, K_38, K_39, K_40, K_42, K_43, K_44, K_45, K_46, K_47, K_48, K_49, K_50, K_51, K_52, K_53, K_55, K_56, K_57, K_58, K_59, K_60, K_63, K_64, K_65, K_66, K_67, K_68, K_69, K_70, K_71, K_72, K_73, K_74, K_75, K_76, K_77, K_79, K_80, K_81, K_82, K_83, K_84, K_85, K_86, K_87, K_88, K_89, K_91, K_92, K_93, K_94, K_104, K_105, K_106, K_108: KEYSW; MX-1U
K_33, K_107: KEYSW; MX-2U
K_41: KEYSW; MX-1.5U
K_54: KEYSW; MX-ISO
K_61, K_95: KEYSW; MXOnly-2U
K_62: KEYSW; MX-1.75U
K_78, K_96, K_97, K_98, K_100, K_101, K_102, K_103: KEYSW; MX-1.25U
K_90: KEYSW; MX-2.75U
K_99: KEYSW; MX-6.25U
Q1: AO3400A; SOT-23
R1, R6, R7: 10k; R_0805_2012Metric
R2, R3: 5.1k; R_0805_2012Metric
R4, R5: 22; R_0805_2012Metric
R8: 220; R_0805_2012Metric
R10, R11, R12, R13, R14, R15, R16, R17, R18, R19, R20, R21, R22, R23, R24, R25, R26, R27, R28, R29, R30, R31, R32, R33, R34, R35, R36, R37, R38, R39, R40, R41, R42, R43, R44, R45, R46, R47, R48, R49, R50, R51, R52, R53, R54, R55, R56, R57, R58, R59, R60, R61, R62, R63, R64, R65, R66, R67, R68, R69, R70, R71, R72, R73, R74, R75, R76, R77, R78, R79, R80, R81, R82, R83, R84, R85, R86, R87, R88, R89, R90, R91, R92, R93, R94, R95, R96, R97, R98, R99, R100, R101, R102, R103, R104, R105, R106, R107, R108, R109, R110, R111, R112, R113, R114, R115, R116, R117, R118: 120; R_0805_2012Metric
SW1: SW_Push; SKQG-1155865
U1: AT90USB1286-A; TQFP-64_14x14mm_P0.8mm
U2, U3: EC11E18244A5; EC11E18244A5_ALPS
VR1: PTB0143-2010BPB103; PTB01432010BPB103; Mouser Part Number 652-PTB1432010BPB103
Y1: 16MHz; Crystal_SMD_3225-4Pin_3.2x2.5mm

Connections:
+5V: C4.1, C5.1, C6.1, C7.1, F1.2, R1.1, R10.1, R11.1, R12.1, R13.1, R14.1, R15.1, R16.1, R17.1, R18.1, R19.1, R20.1, R21.1, R22.1, R23.1, R24.1, R25.1, R26.1, R27.1, R28.1, R29.1, R30.1, R31.1, R32.1, R33.1, R34.1, R35.1, R36.1, R37.1, R38.1, R39.1, R40.1, R41.1, R42.1, R43.1, R44.1, R45.1, R46.1, R47.1, R48.1, R49.1, R50.1, R51.1, R52.1, R53.1, R54.1, R55.1, R56.1, R57.1, R58.1, R59.1, R60.1, R61.1, R62.1, R63.1, R64.1, R65.1, R66.1, R67.1, R68.1, R69.1, R70.1, R71.1, R72.1, R73.1, R74.1, R75.1, R76.1, R77.1, R78.1, R79.1, R80.1, R81.1, R82.1, R83.1, R84.1, R85.1, R86.1, R87.1, R88.1, R89.1, R90.1, R91.1, R92.1, R93.1, R94.1, R95.1, R96.1, R97.1, R98.1, R99.1, R100.1, R101.1, R102.1, R103.1, R104.1, R105.1, R106.1, R107.1, R108.1, R109.1, R110.1, R111.1, R112.1, R113.1, R114.1, R115.1, R116.1, R117.1, R118.1, U1.3 (UVCC), U1.8 (VBUS), U1.21 (VCC), U1.52 (VCC), U1.64 (AVCC), VR1.3 (CW)
/D+: J1.A6 (D+), J1.B6 (D+), R4.1
/D-: J1.A7 (D-), J1.B7 (D-), R5.1
GND: C1.1, C2.1, C3.2, C4.2, C5.2, C6.2, C7.2, J1.A1 (GND), J1.A12 (GND), J1.B1 (GND), J1.B12 (GND), J1.S1 (SHIELD), Q1.2 (S), R2.1, R3.2, R6.1, R7.1, SW1.1, U1.6 (UGND), U1.22 (GND), U1.53 (GND), U1.63 (GND), U2.C, U2.E, U3.C, U3.E, VR1.1 (CCW), VR1.MH1, VR1.MH2, Y1.2, Y1.4
LED-: K_0.4 (LEDGND), K_1.4 (LEDGND), K_2.4 (LEDGND), K_3.4 (LEDGND), K_4.4 (LEDGND), K_5.4 (LEDGND), K_6.4 (LEDGND), K_7.4 (LEDGND), K_8.4 (LEDGND), K_9.4 (LEDGND), K_10.4 (LEDGND), K_11.4 (LEDGND), K_12.4 (LEDGND), K_13.4 (LEDGND), K_14.4 (LEDGND), K_15.4 (LEDGND), K_16.4 (LEDGND), K_17.4 (LEDGND), K_18.4 (LEDGND), K_19.4 (LEDGND), K_20.4 (LEDGND), K_21.4 (LEDGND), K_22.4 (LEDGND), K_23.4 (LEDGND), K_24.4 (LEDGND), K_25.4 (LEDGND), K_26.4 (LEDGND), K_27.4 (LEDGND), K_28.4 (LEDGND), K_29.4 (LEDGND), K_30.4 (LEDGND), K_31.4 (LEDGND), K_32.4 (LEDGND), K_33.4 (LEDGND), K_34.4 (LEDGND), K_35.4 (LEDGND), K_36.4 (LEDGND), K_37.4 (LEDGND), K_38.4 (LEDGND), K_39.4 (LEDGND), K_40.4 (LEDGND), K_41.4 (LEDGND), K_42.4 (LEDGND), K_43.4 (LEDGND), K_44.4 (LEDGND), K_45.4 (LEDGND), K_46.4 (LEDGND), K_47.4 (LEDGND), K_48.4 (LEDGND), K_49.4 (LEDGND), K_50.4 (LEDGND), K_51.4 (LEDGND), K_52.4 (LEDGND), K_53.4 (LEDGND), K_54.4 (LEDGND), K_55.4 (LEDGND), K_56.4 (LEDGND), K_57.4 (LEDGND), K_58.4 (LEDGND), K_59.4 (LEDGND), K_60.4 (LEDGND), K_61.4 (LEDGND), K_62.4 (LEDGND), K_63.4 (LEDGND), K_64.4 (LEDGND), K_65.4 (LEDGND), K_66.4 (LEDGND), K_67.4 (LEDGND), K_68.4 (LEDGND), K_69.4 (LEDGND), K_70.4 (LEDGND), K_71.4 (LEDGND), K_72.4 (LEDGND), K_73.4 (LEDGND), K_74.4 (LEDGND), K_75.4 (LEDGND), K_76.4 (LEDGND), K_77.4 (LEDGND), K_78.4 (LEDGND), K_79.4 (LEDGND), K_80.4 (LEDGND), K_81.4 (LEDGND), K_82.4 (LEDGND), K_83.4 (LEDGND), K_84.4 (LEDGND), K_85.4 (LEDGND), K_86.4 (LEDGND), K_87.4 (LEDGND), K_88.4 (LEDGND), K_89.4 (LEDGND), K_90.4 (LEDGND), K_91.4 (LEDGND), K_92.4 (LEDGND), K_93.4 (LEDGND), K_94.4 (LEDGND), K_95.4 (LEDGND), K_96.4 (LEDGND), K_97.4 (LEDGND), K_98.4 (LEDGND), K_99.4 (LEDGND), K_100.4 (LEDGND), K_101.4 (LEDGND), K_102.4 (LEDGND), K_103.4 (LEDGND), K_104.4 (LEDGND), K_105.4 (LEDGND), K_106.4 (LEDGND), K_107.4 (LEDGND), K_108.4 (LEDGND), Q1.3 (D)
unnamed: D_0.2 (A), K_0.2 (ROW)
unnamed: D_1.2 (A), K_1.2 (ROW)
unnamed: D_2.2 (A), K_2.2 (ROW)
unnamed: D_3.2 (A), K_3.2 (ROW)
unnamed: D_4.2 (A), K_4.2 (ROW)
unnamed: D_5.2 (A), K_5.2 (ROW)
unnamed: D_6.2 (A), K_6.2 (ROW)
unnamed: D_7.2 (A), K_7.2 (ROW)
unnamed: D_8.2 (A), K_8.2 (ROW)
unnamed: D_9.2 (A), K_9.2 (ROW)
unnamed: D_10.2 (A), K_10.2 (ROW)
unnamed: D_11.2 (A), K_11.2 (ROW)
unnamed: D_12.2 (A), K_12.2 (ROW)
unnamed: D_13.2 (A), K_13.2 (ROW)
unnamed: D_14.2 (A), K_14.2 (ROW)
unnamed: D_15.2 (A), K_15.2 (ROW)
unnamed: D_16.2 (A), K_16.2 (ROW)
unnamed: D_17.2 (A), K_17.2 (ROW)
unnamed: D_18.2 (A), K_18.2 (ROW)
unnamed: D_19.2 (A), K_19.2 (ROW)
unnamed: D_20.2 (A), K_20.2 (ROW)
unnamed: D_21.2 (A), K_21.2 (ROW)
unnamed: D_22.2 (A), K_22.2 (ROW)
unnamed: D_23.2 (A), K_23.2 (ROW)
unnamed: D_24.2 (A), K_24.2 (ROW)
unnamed: D_25.2 (A), K_25.2 (ROW)
unnamed: D_26.2 (A), K_26.2 (ROW)
unnamed: D_27.2 (A), K_27.2 (ROW)
unnamed: D_28.2 (A), K_28.2 (ROW)
unnamed: D_29.2 (A), K_29.2 (ROW)
unnamed: D_30.2 (A), K_30.2 (ROW)
unnamed: D_31.2 (A), K_31.2 (ROW)
unnamed: D_32.2 (A), K_32.2 (ROW)
unnamed: D_33.2 (A), K_33.2 (ROW)
unnamed: D_34.2 (A), K_34.2 (ROW)
unnamed: D_35.2 (A), K_35.2 (ROW)
unnamed: D_36.2 (A), K_36.2 (ROW)
unnamed: D_37.2 (A), K_37.2 (ROW)
unnamed: D_38.2 (A), K_38.2 (ROW)
unnamed: D_39.2 (A), K_39.2 (ROW)
unnamed: D_40.2 (A), K_40.2 (ROW)
unnamed: D_41.2 (A), K_41.2 (ROW)
unnamed: D_42.2 (A), K_42.2 (ROW)
unnamed: D_43.2 (A), K_43.2 (ROW)
unnamed: D_44.2 (A), K_44.2 (ROW)
unnamed: D_45.2 (A), K_45.2 (ROW)
unnamed: D_46.2 (A), K_46.2 (ROW)
unnamed: D_47.2 (A), K_47.2 (ROW)
unnamed: D_48.2 (A), K_48.2 (ROW)
unnamed: D_49.2 (A), K_49.2 (ROW)
unnamed: D_50.2 (A), K_50.2 (ROW)
unnamed: D_51.2 (A), K_51.2 (ROW)
unnamed: D_52.2 (A), K_52.2 (ROW)
unnamed: D_53.2 (A), K_53.2 (ROW)
unnamed: D_54.2 (A), K_54.2 (ROW)
unnamed: D_55.2 (A), K_55.2 (ROW)
unnamed: D_56.2 (A), K_56.2 (ROW)
unnamed: D_57.2 (A), K_57.2 (ROW)
unnamed: D_58.2 (A), K_58.2 (ROW)
unnamed: D_59.2 (A), K_59.2 (ROW)
unnamed: D_60.2 (A), K_60.2 (ROW)
unnamed: D_61.2 (A), K_61.2 (ROW)
unnamed: D_62.2 (A), K_62.2 (ROW)
unnamed: D_63.2 (A), K_63.2 (ROW)
unnamed: D_64.2 (A), K_64.2 (ROW)
unnamed: D_65.2 (A), K_65.2 (ROW)
unnamed: D_66.2 (A), K_66.2 (ROW)
unnamed: D_67.2 (A), K_67.2 (ROW)
unnamed: D_68.2 (A), K_68.2 (ROW)
unnamed: D_69.2 (A), K_69.2 (ROW)
unnamed: D_70.2 (A), K_70.2 (ROW)
unnamed: D_71.2 (A), K_71.2 (ROW)
unnamed: D_72.2 (A), K_72.2 (ROW)
unnamed: D_73.2 (A), K_73.2 (ROW)
unnamed: D_74.2 (A), K_74.2 (ROW)
unnamed: D_75.2 (A), K_75.2 (ROW)
unnamed: D_76.2 (A), K_76.2 (ROW)
unnamed: D_77.2 (A), K_77.2 (ROW)
unnamed: D_78.2 (A), K_78.2 (ROW)
unnamed: D_79.2 (A), K_79.2 (ROW)
unnamed: D_80.2 (A), K_80.2 (ROW)
unnamed: D_81.2 (A), K_81.2 (ROW)
unnamed: D_82.2 (A), K_82.2 (ROW)
unnamed: D_83.2 (A), K_83.2 (ROW)
unnamed: D_84.2 (A), K_84.2 (ROW)
unnamed: D_85.2 (A), K_85.2 (ROW)
unnamed: D_86.2 (A), K_86.2 (ROW)
unnamed: D_87.2 (A), K_87.2 (ROW)
unnamed: D_88.2 (A), K_88.2 (ROW)
unnamed: D_89.2 (A), K_89.2 (ROW)
unnamed: D_90.2 (A), K_90.2 (ROW)
unnamed: D_91.2 (A), K_91.2 (ROW)
unnamed: D_92.2 (A), K_92.2 (ROW)
unnamed: D_93.2 (A), K_93.2 (ROW)
unnamed: D_94.2 (A), K_94.2 (ROW)
unnamed: D_95.2 (A), K_95.2 (ROW)
unnamed: D_96.2 (A), K_96.2 (ROW)
unnamed: D_97.2 (A), K_97.2 (ROW)
unnamed: D_98.2 (A), K_98.2 (ROW)
unnamed: D_99.2 (A), K_99.2 (ROW)
unnamed: D_100.2 (A), K_100.2 (ROW)
unnamed: D_101.2 (A), K_101.2 (ROW)
unnamed: D_102.2 (A), K_102.2 (ROW)
unnamed: D_103.2 (A), K_103.2 (ROW)
unnamed: D_104.2 (A), K_104.2 (ROW)
unnamed: D_105.2 (A), K_105.2 (ROW)
unnamed: D_106.2 (A), K_106.2 (ROW)
unnamed: D_107.2 (A), K_107.2 (ROW)
unnamed: D_108.2 (A), K_108.2 (ROW)
unnamed: J1.A5 (CC1), R2.2
unnamed: J1.B5 (CC2), R3.1
unnamed: K_0.3 (LED), R10.2
unnamed: K_1.3 (LED), R29.2
unnamed: K_2.3 (LED), R28.2
unnamed: K_3.3 (LED), R27.2
unnamed: K_4.3 (LED), R26.2
unnamed: K_5.3 (LED), R25.2
unnamed: K_6.3 (LED), R24.2
unnamed: K_7.3 (LED), R23.2
unnamed: K_8.3 (LED), R22.2
unnamed: K_9.3 (LED), R21.2
unnamed: K_10.3 (LED), R20.2
unnamed: K_11.3 (LED), R19.2
unnamed: K_12.3 (LED), R18.2
unnamed: K_13.3 (LED), R17.2
unnamed: K_14.3 (LED), R16.2
unnamed: K_15.3 (LED), R15.2
unnamed: K_16.3 (LED), R14.2
unnamed: K_17.3 (LED), R13.2
unnamed: K_18.3 (LED), R12.2
unnamed: K_19.3 (LED), R11.2
unnamed: K_20.3 (LED), R30.2
unnamed: K_21.3 (LED), R31.2
unnamed: K_22.3 (LED), R32.2
unnamed: K_23.3 (LED), R33.2
unnamed: K_24.3 (LED), R34.2
unnamed: K_25.3 (LED), R35.2
unnamed: K_26.3 (LED), R36.2
unnamed: K_27.3 (LED), R37.2
unnamed: K_28.3 (LED), R38.2
unnamed: K_29.3 (LED), R39.2
unnamed: K_30.3 (LED), R40.2
unnamed: K_31.3 (LED), R41.2
unnamed: K_32.3 (LED), R42.2
unnamed: K_33.3 (LED), R43.2
unnamed: K_34.3 (LED), R44.2
unnamed: K_35.3 (LED), R45.2
unnamed: K_36.3 (LED), R46.2
unnamed: K_37.3 (LED), R47.2
unnamed: K_38.3 (LED), R48.2
unnamed: K_39.3 (LED), R49.2
unnamed: K_40.3 (LED), R50.2
unnamed: K_41.3 (LED), R71.2
unnamed: K_42.3 (LED), R70.2
unnamed: K_43.3 (LED), R69.2
unnamed: K_44.3 (LED), R68.2
unnamed: K_45.3 (LED), R67.2
unnamed: K_46.3 (LED), R66.2
unnamed: K_47.3 (LED), R65.2
unnamed: K_48.3 (LED), R64.2
unnamed: K_49.3 (LED), R63.2
unnamed: K_50.3 (LED), R62.2
unnamed: K_51.3 (LED), R61.2
unnamed: K_52.3 (LED), R60.2
unnamed: K_53.3 (LED), R59.2
unnamed: K_54.3 (LED), R58.2
unnamed: K_55.3 (LED), R57.2
unnamed: K_56.3 (LED), R56.2
unnamed: K_57.3 (LED), R55.2
unnamed: K_58.3 (LED), R54.2
unnamed: K_59.3 (LED), R53.2
unnamed: K_60.3 (LED), R52.2
unnamed: K_61.3 (LED), R51.2
unnamed: K_62.3 (LED), R72.2
unnamed: K_63.3 (LED), R73.2
unnamed: K_64.3 (LED), R74.2
unnamed: K_65.3 (LED), R75.2
unnamed: K_66.3 (LED), R76.2
unnamed: K_67.3 (LED), R77.2
unnamed: K_68.3 (LED), R78.2
unnamed: K_69.3 (LED), R79.2
unnamed: K_70.3 (LED), R80.2
unnamed: K_71.3 (LED), R81.2
unnamed: K_72.3 (LED), R82.2
unnamed: K_73.3 (LED), R83.2
unnamed: K_74.3 (LED), R84.2
unnamed: K_75.3 (LED), R85.2
unnamed: K_76.3 (LED), R86.2
unnamed: K_77.3 (LED), R87.2
unnamed: K_78.3 (LED), R105.2
unnamed: K_79.3 (LED), R104.2
unnamed: K_80.3 (LED), R103.2
unnamed: K_81.3 (LED), R102.2
unnamed: K_82.3 (LED), R101.2
unnamed: K_83.3 (LED), R100.2
unnamed: K_84.3 (LED), R99.2
unnamed: K_85.3 (LED), R98.2
unnamed: K_86.3 (LED), R97.2
unnamed: K_87.3 (LED), R96.2
unnamed: K_88.3 (LED), R95.2
unnamed: K_89.3 (LED), R94.2
unnamed: K_90.3 (LED), R93.2
unnamed: K_91.3 (LED), R92.2
unnamed: K_92.3 (LED), R91.2
unnamed: K_93.3 (LED), R90.2
unnamed: K_94.3 (LED), R89.2
unnamed: K_95.3 (LED), R88.2
unnamed: K_96.3 (LED), R106.2
unnamed: K_97.3 (LED), R107.2
unnamed: K_98.3 (LED), R108.2
unnamed: K_99.3 (LED), R109.2
unnamed: K_100.3 (LED), R110.2
unnamed: K_101.3 (LED), R111.2
unnamed: K_102.3 (LED), R112.2
unnamed: K_103.3 (LED), R113.2
unnamed: K_104.3 (LED), R114.2
unnamed: K_105.3 (LED), R115.2
unnamed: K_106.3 (LED), R116.2
unnamed: K_107.3 (LED), R117.2
unnamed: K_108.3 (LED), R118.2
unnamed: Q1.1 (G), R7.2, R8.2
unnamed: R4.2, U1.5 (D+)
unnamed: R5.2, U1.4 (D-)
unnamed: R8.1, U1.28 (PD3)
unnamed: R6.2, U1.43 (PE2/~HWB)
unnamed: C3.1, U1.7 (UCAP)
unnamed: C1.2, U1.24 (XTAL1), Y1.1
unnamed: C2.2, U1.23 (XTAL2), Y1.3
unnamed: R1.2, SW1.2, U1.20 (~RESET)
PC1: U1.36 (PC1), U2.A
PC2: U1.37 (PC2), U2.B
PC3: U1.38 (PC3), U2.D
PC4: U1.39 (PC4), U3.A
PC5: U1.40 (PC5), U3.B
PC6: U1.41 (PC6), U3.D
PF0: U1.61 (PF0), VR1.2 (WIPER_)
VCC: F1.1, J1.A4 (VBUS), J1.A9 (VBUS), J1.B4 (VBUS), J1.B9 (VBUS)
col0: K_0.1 (COL), K_20.1 (COL), K_41.1 (COL), K_62.1 (COL), K_78.1 (COL), K_96.1 (COL), U1.30 (PD5)
col1: K_21.1 (COL), K_79.1 (COL), K_97.1 (COL), U1.55 (PF6)
col2: K_1.1 (COL), K_22.1 (COL), K_42.1 (COL), K_63.1 (COL), K_80.1 (COL), U1.56 (PF5)
col3: K_2.1 (COL), K_23.1 (COL), K_43.1 (COL), K_64.1 (COL), K_81.1 (COL), K_98.1 (COL), U1.57 (PF4)
col4: K_3.1 (COL), K_24.1 (COL), K_44.1 (COL), K_65.1 (COL), K_82.1 (COL), U1.10 (PB0)
col5: K_4.1 (COL), K_25.1 (COL), K_45.1 (COL), K_66.1 (COL), K_83.1 (COL), U1.29 (PD4)
col6: K_26.1 (COL), K_46.1 (COL), K_67.1 (COL), K_84.1 (COL), K_99.1 (COL), U1.11 (PB1)
col7: K_5.1 (COL), K_27.1 (COL), K_47.1 (COL), K_68.1 (COL), K_85.1 (COL), U1.12 (PB2)
col8: K_6.1 (COL), K_28.1 (COL), K_48.1 (COL), K_69.1 (COL), K_86.1 (COL), U1.13 (PB3)
col9: K_7.1 (COL), K_29.1 (COL), K_49.1 (COL), K_70.1 (COL), K_87.1 (COL), U1.14 (PB4)
col10: K_8.1 (COL), K_30.1 (COL), K_50.1 (COL), K_71.1 (COL), K_88.1 (COL), K_100.1 (COL), U1.15 (PB5)
col11: K_9.1 (COL), K_31.1 (COL), K_51.1 (COL), K_72.1 (COL), K_89.1 (COL), K_101.1 (COL), U1.16 (PB6)
col12: K_10.1 (COL), K_32.1 (COL), K_52.1 (COL), K_73.1 (COL), U1.17 (PB7)
col13: K_11.1 (COL), K_53.1 (COL), K_74.1 (COL), K_90.1 (COL), K_102.1 (COL), U1.31 (PD6)
col14: K_12.1 (COL), K_33.1 (COL), K_54.1 (COL), K_103.1 (COL), U1.32 (PD7)
col15: K_13.1 (COL), K_34.1 (COL), K_55.1 (COL), K_104.1 (COL), U1.58 (PF3)
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

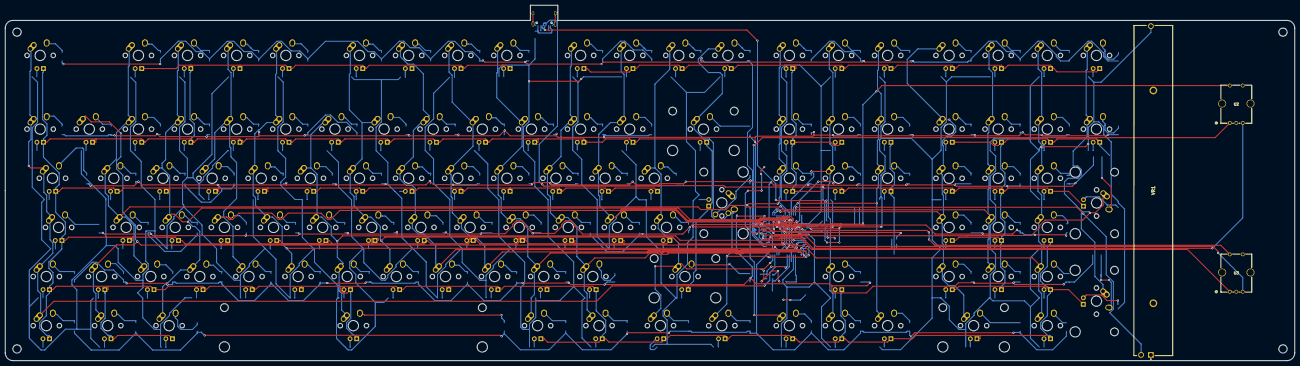
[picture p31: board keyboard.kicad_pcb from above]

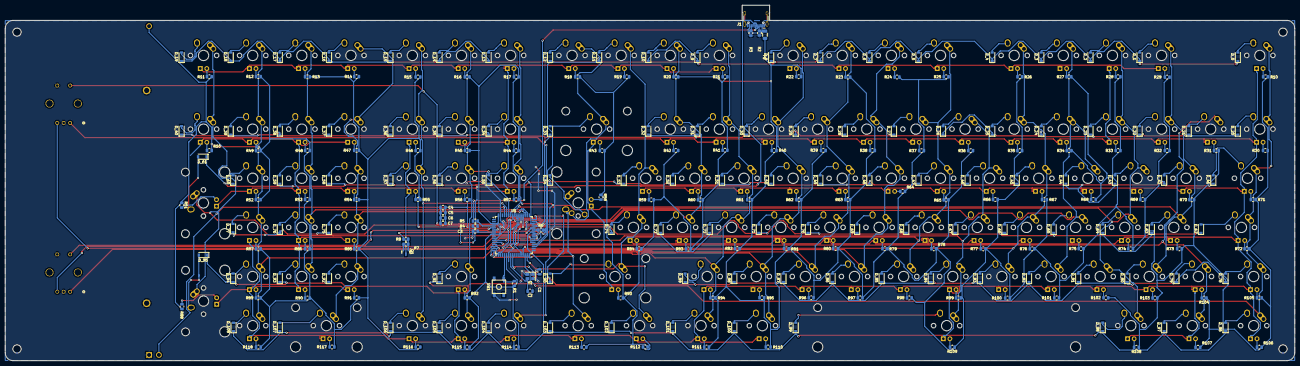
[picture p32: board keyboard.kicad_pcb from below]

Board: 2 copper layers, 500.0 x 137.8 mm, 351 parts (239 on the bottom side), 270 nets.

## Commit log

2025-05-22 Layout + wiring
2025-05-24 Add screw holes to case
    [Case.step, MacPad.step, Top MacPad.stl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]
2025-05-24 Update BOM
    [BOM.csv]
2025-05-26 Fix PCB
    [keyboard.kicad_sch]
2025-05-29 Update PCB
2025-05-29 Case upgrades
    [Keyboard.step, Keyboard.stl]
2025-05-31 3d model
    [Keyboard Base.stl, Keyboard lid.stl, Keyboard.stl]
